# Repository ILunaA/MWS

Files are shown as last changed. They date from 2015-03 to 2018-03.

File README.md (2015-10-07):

MWS
===

Arduino code for a Mobile Weather Station

This is using the SparkFun Weather Shield (https://www.sparkfun.com/products/12081).

Full building manuals in English, Sinhalese and Tamil are found here (along with some display/presentation materials):
http://www.iwmi.cgiar.org/resources/mobile-weather-stations/

There is a Google Group at: IWMIMWS@googlegroups.com

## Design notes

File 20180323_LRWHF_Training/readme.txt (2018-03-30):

This code was made during the training in Sri lanka by the participants.
It adds Dewpoint reporting, heat Index and rain30min.

This is made for non GSM enabled setup (i.e. Arduino Mega, Weather Shield and GPS connected to it).

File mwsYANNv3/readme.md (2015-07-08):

General info about the set up:
- Arduino Mega (x1)
- Sparkfun.com Weather Shield (https://www.sparkfun.com/products/12081)

Optional (plug n play):
- Sparkfun.com (https://www.sparkfun.com/products/9530)
- Generic LCD16x02 with I2C adaptor (more here: http://arduino-info.wikispaces.com/LCD-Blue-I2C)

Required male-to-male cables:
- I2C sensors: Weather Shield A4 to Arduino Mega Pin20 (SDA)
- I2C sensors: Weather Shield A5 to Arduino Mega Pin21 (SCL)
- I2C LCD SDA to Arduino Mega Pin20 (SDA)
- I2C LCD SCL to Arduino Mega Pin21 (SCL)
- COM GPS: Weather Shield PIN4 to Arduino Mega Pin51
- COM GPS: Weather Shield PIN5 to Arduino Mega Pin50

GPS "soft" switch mode:
- Communicates through D4/D5 (same as Arduino Uno R3)
- Power Control through D6 (same as Arduino Uno R3)
- D4/D5/D6 on Arduino Uno (spec sheet: T0/T1/AIN0)
- D7/D6/D5 on Arduino Mega (spec sheet: T0/T1/AIN1*)

*could not find AIN0 pin number in the Mega spec sheet

From https://www.arduino.cc/en/Reference/SoftwareSerial :
- Not all pins on the Mega and Mega 2560 support change interrupts
- so only the following can be used for RX: 
- 10, 11, 12, 13, 14, 15, 50, 51, 52, 53, 
- A8 (62), A9 (63), A10 (64), A11 (65), A12 (66), A13 (67), A14 (68), A15 (69).

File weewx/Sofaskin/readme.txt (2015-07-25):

Arduino restarts each time the Serial port is opened
----------------------------------------------------

Try:
A 10microF capacitor between pin RESET and pin GND to disable that function hardware side.
http://arduino.stackexchange.com/questions/439/why-does-starting-the-serial-monitor-restart-the-sketch

Copy mws.py in $weewxroot/bin/user/ (in RPI it will be /home/weewx/bin/user/) 

Add to $weewxroot/weewx.conf (in RPI it will be /home/weewx/weewx.conf):
------------------------------------------------------------------------

station_type = MWS #was: Simulator

##############################################################################

[MWS]
    
    # Use a non standard driver called mws
    driver = user.mws
    # Give a 5 minute interval for data storage
    loop_interval = 300
    # RPI has this port detected
    port='/dev/ttyACM0'

##############################################################################

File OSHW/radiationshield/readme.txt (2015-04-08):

http://www.thingiverse.com/thing:83969

Description

A Stevenson screen is an outdoor shelter for your meteorological sensors, such as those that come along with your electronic home weather station. The World Meteorological Organization (WMO) agreed standard for the height of the screen is between 1.25 m (4ft 1 in) and 2 m (6ft 7 in). Its purpose is to provide a standardized environment in which to measure temperature, humidity, dew point and atmospheric pressure. The louvered design allows for the instrument to be sheltered from direct sunlight and rain, yet air is able to flow through the screen unrestricted.

Instructions

Print out one top-part and one bottom-part, and then as many middle-parts as necessary. The parts are designed to snap together (inspired by tbuser's Pin Connectors), so no tools required for assembly. The Stevenson screen is designed to be placed on a pole; one wood-screw and a washer required. The pole in the pictures is a Kelleher 6 ft white vinyl coated closet pole acquired from a local home improvement store.

IMPORTANT: Please print in WHITE color in accordance to the WMO agreed standard.

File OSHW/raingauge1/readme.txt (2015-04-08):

http://www.thingiverse.com/thing:298411

Description

Add your own hall/reed sensor and magnet and of-course the electronics and you can create a remote rain sensor system.

Suggested electronics; Arduino & A1301 hall effect sensor.

See: http://playground.arduino.cc/Code/HallEffect

Included funnel & box for sensor.

You might want to tweak the box size so that the funnel fits over the box.

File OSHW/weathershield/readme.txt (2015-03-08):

This is Sparkfun Weather Shield blueprints, an electronic engineer can build or order a factory to make such circuits for you.

Downloaded from:
https://www.sparkfun.com/products/12081

In Sri Lanka, A&T Labs (http://www.atlabslanka.com/) has some.

on March 8th, 2015

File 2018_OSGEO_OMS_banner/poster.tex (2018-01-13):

\documentclass[25pt, margin=0mm, innermargin=15mm, blockverticalspace=15mm, colspace=15mm, subcolspace=8mm]{beamer}
\geometry{paperwidth=40cm,paperheight=181cm}

% to stretch boxes over whole paper with custor paper size
\makeatletter
\setlength{\TP@visibletextwidth}{\textwidth-2\TP@innermargin}
\setlength{\TP@visibletextheight}{\textheight-2\TP@innermargin}
\makeatother

\usepackage{fix-cm}  
\makeatletter
\newcommand\HUGE{\@setfontsize\Huge{80}{90}}
\makeatother

\usepackage{wrapfig}

\definecolor{textcolor}{HTML}{000000}
\definecolor{colorOne}{HTML}{4cbf5d}
\definecolor{colorTwo}{HTML}{dddddd}
\definecolor{colorThree}{HTML}{12343a}

\hypersetup
{
    pdfauthor={Y. Chemin},
    pdfsubject={},
    pdftitle={Open Monitoring Systems Working Group},
    pdfkeywords={}
}

\graphicspath{{images/}{logos/}}

\usepackage[percent]{overpic}
\usepackage{tikz}
\tikzset{
  every overlay node/.style={
    draw=white,fill=white,rounded corners,anchor=north west,
  },
}
% Usage:
% \tikzoverlay at (-1cm,-5cm) {content};
% or
% \tikzoverlay[text width=5cm] at (-1cm,-5cm) {content};
\def\tikzoverlay{%
   \tikz[baseline,overlay]\node[every overlay node]
}%

\begin{document}

\tikzoverlay at (-1.2cm,1.2cm) {
\begin{tikzpicture}
   % NODES
   \node (r0) at (40.0,  0.0) {}; % root
   \node (s0) at (20.0, -160.0) {}; % extreme
   \node (s1) at (40.0, -180.0) {}; % extreme

   % DRAW TREE
   \fill[fill=colorThree,colorThree] (r0.center)--(s0.center)--(s1.center);
   \path[draw] (r0)--(s0);
   \path[draw] (s0)--(s1);
   \path[draw] (s1)--(r0);

   % NODES
   \node (r1) at (-0.1,  -100.5) {}; % root
   \node (s10) at (40.3, -220.0) {}; % extreme
   \node (s11) at (50.0, -165.0) {}; % extreme

   % DRAW TREE
   \fill[fill=colorOne,colorOne] (r1.center)--(s10.center)--(s11.center);
   \path[draw] (r1)--(s10);
   \path[draw] (s10)--(s11);
   \path[draw] (s11)--(r1);

\end{tikzpicture}
}

\tikzoverlay at (5cm,-35cm){
\begin{tikzpicture}[overlay]
\node at (current page.south west) [above right, inner sep=0,outer sep=0]
	{};
\end{tikzpicture}
}

\tikzoverlay at (5cm,-55cm){
\begin{tikzpicture}[overlay]
	\node at (current page.south west) [above right,text width=40cm,align=left] {\HUGE{\textbf{\color{colorThree}Open \\Monitoring \\Systems \\Working Group}}};
\end{tikzpicture}
}

\tikzoverlay at (5cm,-70cm){
\begin{tikzpicture}[overlay]
	\node at (current page.south west) [above right,text width=40cm,align=left] {\Huge{\color{colorThree}https://wiki.osgeo.org/wiki/Open\_Monitoring\_Systems\_Working\_Group}};
\end{tikzpicture}
}

\tikzoverlay at (-1.2cm,-181cm){
\begin{tikzpicture}[overlay]
\node at (current page.south west) [above right, inner sep=0,outer sep=0]
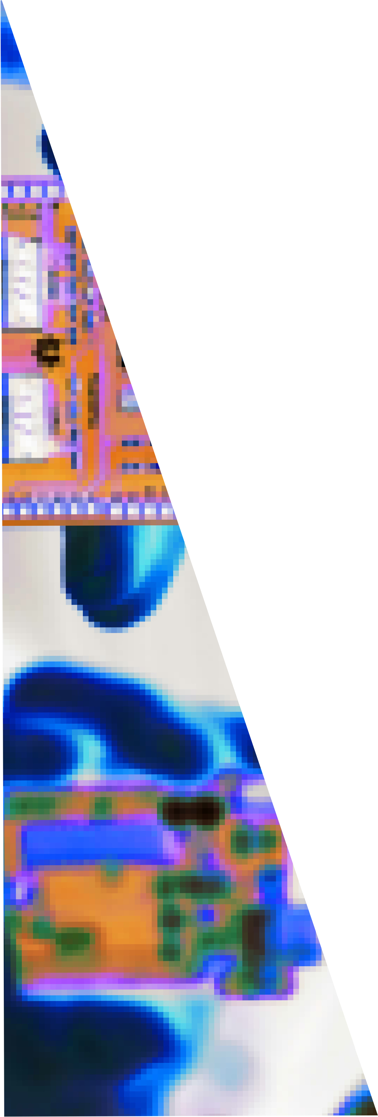
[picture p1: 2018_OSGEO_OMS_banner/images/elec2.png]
	{};
\end{tikzpicture}
}

\tikzoverlay at (-1.2cm,1.2cm) {
\begin{tikzpicture}[overlay]
	\draw [draw=green,thick] (0,-100) (20.0,-160.0);
\end{tikzpicture}
}
%%%%%%%%%%%%%%%%%%%%%%%%%%%%%%%%%%%%%%%%%%%%%%%%%%%%%%%%%%%%%%%%%%%%%%%%%%%%%%%%

\end{document}

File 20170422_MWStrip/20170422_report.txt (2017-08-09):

UO_NUWARAWEWA_SALIYAPURA:
1 - Concrete for raingauge upgrade not made.
2 - Station running.
3 - Signs of aging of external sensors, but still running.
4 - SD card has empty files (why? TODO: check updated code from Lahiru/David trips
5 - We cleaned the rain gauge and solar panels and manually tripped the rain gauge about 70 times to test the threshold value and see if a message was sent. This data point should be ignored.

UO_MAHAKANADARAWA:
1 - Concrete for raingauge upgrade not made.
2 - Station reset, running after replacing the solar charger. 
3 - Wire connections to solar charger must be pushed all the way to the back of the connection sockets to achieve a good connection. Station was previously not receiving adequate power due to a poor connection to charger. This was tested with a multimeter.
4 - Signs of aging on external sensors, but still operational.
5 - Nothing useful in SD card
6 - Solar panel reoriented to face west, which was least blocked by trees. Sunlight will strike more directly, but only afternoons.

THIRAPPANE_FARM:
1 - Concrete for raingauge upgrade not made.
2 - Solar charger was set to mode 3 and not mode 16
3 - Station reset, solar charger set to mode 16, running.
4 - Sensors less aged, their cables more.
5 - SD card not found by laptop, nor mobile, must be broken, was replaced.
6 - Screws on box were too small and not holding box shut, replaced.

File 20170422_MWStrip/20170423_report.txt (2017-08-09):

UO_ATHURUWELLA:
1 - Concrete for raingauge upgrade not made.
2 - Station reset, running after fitting the cables again into the solar charger output.
3 - Signs of aging of external sensors, but still running.
4 - SD card has empty files, but station has been switched off most of the time. 
5 - SIM card has 1090LKR inside still.
6 - Clean rain gauge internals, solar panels are also clean and manually tripped the rain gauge about 50 times to test the threshold value and see if a message was sent. We did not receive it. 
7 - Planned to return on Monday with journalists.
8 - Added a GSM antenna inside, upated code, initialising message received, but once closed box, the manual tipping alert was not received. Will change external antenna.

UO_LABUNORUWA_WEWA_N_WANA:
1 - UO was abandoned more than a year ago (source: neighbour)
2 - We found that wind sensors where vandalised and the moving parts removed
3 - we unbolted the main frame holding solar panel + box and brought it back in the car.
4 - This station name should be removed from list
5 - This system was still working inside (Power optimal, Arduino on, GSM OK), but data logger had not meaningful info stored.

SRI_SADANANDA_PIRIVENA:
1 - The power supply was on MODE 17, we put it back to MODE 16 for automatic operation.
2 - Arduino powered optimally
3 - GSM900a external board (small size) is blinking but not report. SIM card dead, replaced by UO_LABUNORU_WENA_N_WANA card (#4: 0773260142)
4 - Even after replacement of SIM card, no initiliazation message
5 - TODO: return with box salvaged from UO_LABUNORUWA_WEWA_N_WANA, and make use of that system.

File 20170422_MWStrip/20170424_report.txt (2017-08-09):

UO_ATHURUWELLA:
1 - Concrete for raingauge upgrade not made. They know now, and will make (when?).
2 - Station reset from A'Pura hotel, but stuck again on the site, finally running after changing the whole external antenna. Removed internal antenna.
3 - Journalists came the whole morning, they got some talks and practiced building themselves.

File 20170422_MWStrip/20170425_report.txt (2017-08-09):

UO_ATHURUWELLA:
1 - Concrete for raingauge upgrade not made. They know now, and will make (when?).
2 - At 1PM station started to have a raingauge glitch, reported rainfall 2500 mm/h about in the next 3 hours. Fixed by installing new raingauge (rectangle, old one).

SRI_SADANANDA_PIRIVENA:
1 - Used the box from UO_LABUNORUWA_WEWA_N_WANA, installed it there.
2 - the old box (black VCR) has suffered water inside, I might discard it here after recovering electronics from it.

NALLAMUDAWA_MAWATHAWEWA:
1 - Recovered the box today from the station.
2 - upgraded the capacitors on the regulator out
3 - Box working in hotel, will deliver tomorrow on site.

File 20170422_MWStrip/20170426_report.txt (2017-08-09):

UO_ATHURUWELLA:
1 - Concrete for raingauge upgrade to be cast tomorrow.
2 - At 12.30 station started to have a raingauge glitch, reported rainfall 2500-4000 mm/h about in the next 3 hours. Got the station to the hotel.
3 - Changed Arduino, added a passive cooler to the chip.
4 - Made holes in the box and added a PC fan, there is less place, so I had to re-manage the location of everything but the batteries.
5 - Will deliver tomorrow and check the concrete work, maybe install the WMO raingauge.

NALLAMUDAWA_MAWATHAWEWA:
1 - Delivered the working box on site.

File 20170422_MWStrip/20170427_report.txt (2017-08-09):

UO_ATHURUWELLA:
1 - Concrete work done today, will go and install WMO-certified raingauge tomorrow.

NALLAMUDAWA_MAWATHAWEWA:
1 - Took the box for service, it did not report this morning.
2 - Changed solar controller, will see if it reports tomorrow morning, then will send it back to field. 

Mahaweli office (80.298011,8.156554, Contact Wajira Mrs, through Lal Muthuwatta):
1 - Took one of the first weather stations to service, it does not have GSM capabilities, just data logging.
2 - Added a regulator to 5V, it was reporting only 13.00 to 14.00, reduced reporting from 5 mins to 1 hour.

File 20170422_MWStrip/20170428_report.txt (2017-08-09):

UO_ATHURUWELLA:
1 - Installed WMO-certified raingauge. All the UO was busy all morning... :-)
2 - Installed the power line from the building and wired it to weather station.

NALLAMUDAWA_MAWATHAWEWA:
1 - Failure again of the solar controller this morning.
2 - Worked on it this afternoon and evening.  

Mahaweli office (80.298011,8.156554, Contact Wajira Mrs, through Lal Muthuwatta):
1 - Returned the weather station, took contacts with tech guys there.
2 - Emailed tech guys and Mrs Wajira further instatructions to upgrade their system.

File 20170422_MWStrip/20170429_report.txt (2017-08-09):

NALLAMUDAWA_MAWATHAWEWA:
1 - Installed station this morning

UO_ATHURUWELLA:
1 - Changed the GPS this morning as it was reporting around 12.30 instead of early morning with 2000-00-01 as a timestamp.
2 - Arrived in Colombo and got another bug message of 321mm/h my guess is that the box is too small, so too warm, we have temperature in the shade of 40 degrees Celsius, we might reach the maximum operation temperature range of the circuit boards as they are not "industrial grade". 
3 - Recommendation 1 for this set up:
I brought back UO_LABUNO solar panel frame, it has a 300x250x120 electric box (IP65) support frame soldered into it,  one could get that from any electrical shop and set it up in replacement of the now too small box, with an additional fan and proper circulation. this will reduce the likelihood of IRQs jumping. 
4 - Recommendation 2 for this set up:
Also, I believe the direct connection of the main power line to the 5V input of the Arduino Mega is giving the system some issues as electric power is often dropped for few hours a day. I have set up a regulator already, but it may not be enough to provide smooth transitions in power in and out.

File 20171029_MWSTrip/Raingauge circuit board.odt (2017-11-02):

Weather sensors with OSHW micro-controllers

Connectivity and circuit-board possibilities

Introduction

We are looking at setting up some basic circuit board connectivity for weather sensors. Since temperature (i.e. DS18B20), humidity (DHT11/22), pressure (BMP180) are very widely covered by online tutorials, and have several open sourced circuit boards available for perousing and PCB making (for example see Sparkfun, 2017), we will concentrate on external sensors, namely rain gauge, wind speed and velocity. Luckily, those three types of sensors, in their simplest incarnations are all reed switch based. A reed switch is a set of two connector bits that are touching each other all the time, unless in the proximity of a magnetic field. Bringing a magnet in the proximity of the reed switch, disconnects the two parts and opens the circuit, thus interrupting power. In the case of external weather sensors, the sensor is a moving part and carries a magnet inside. The wind velocity sensor counts how many turns per amount of time for example. Each time the moving part goes above a reed switch, a signal is sent inside the microcontroller, the number of signals are recorded within the micro-controller by an always listening sub-system called an IRQ (Interrupted Request), a hardware signal sent to the processor that temporarily stops a running program and allows a special program, an interrupt handler, to run instead. The program inside the micro-controller allocates an IRQ function to the PIN to which the sensor reed switch is connected.

The wind direction is different since it is a flower of 8 or 16 reed switches and the internal circuit board of the sensor sends a step-based power strength, which is giving certain values proportional to the wind direction.

The rain gauge is a simple counter, each IRQ is a volume of rainfall received in the tipping bucket, which is proportional to the height of rainfall (mm) in function of the surface area of the rain gauge and the time elapsed.

Arduino and raingauge

Arduino can enable IRQs on its digital pins. The function digitalPinToInterrupt() permits to enable the connection of the pin to the interrupt process. The function attachInterrupt(), actually sets what is happening when the IRQ is triggered (power up: rising, power down: falling) and received at the pin number. Often a function is triggered to accumulate a count of actions (e.g. reed switch clicks in our case).

Simple case: reed switch connection

In this case, the power is given to the Arduino Nano through the 5V VIN pin and the GND round pin. On the way, the reed switch of the rain gauge (or of the anemometer) is plugged from pin D2 to pin GND.

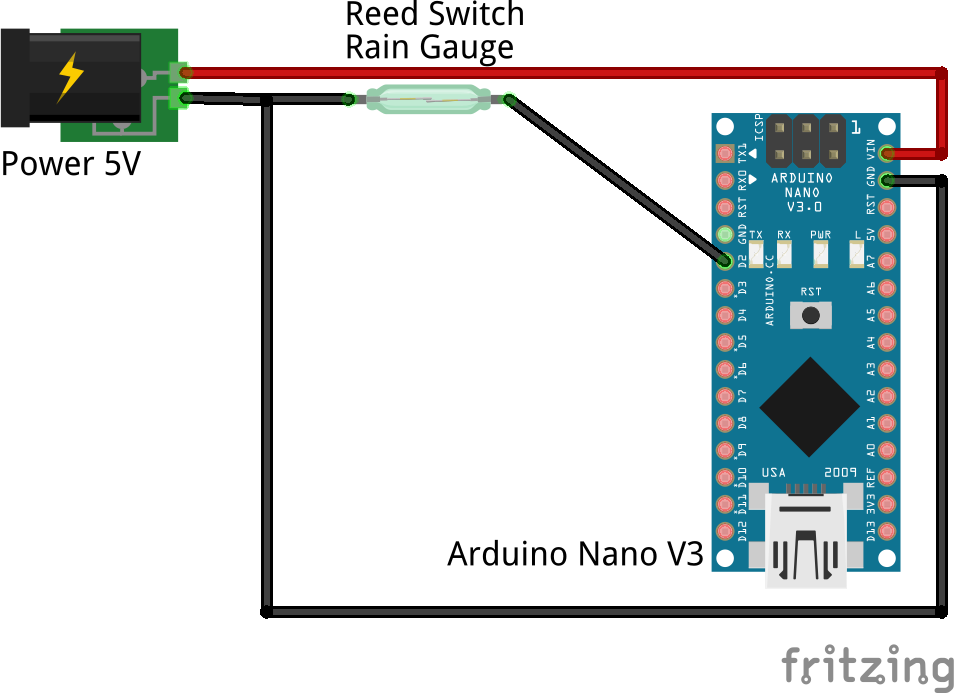
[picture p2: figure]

Figure 1: Connecting a reed switch to Arduino

The corresponding Arduino code is like this:

//Set PIN 2 as data input pulled up

pinMode(2, INPUT_PULLUP);

//Attach IRQ to PIN 2 and tells it to run function addRain()
attachInterrupt (digitalPinToInterrupt(2), addRain, FALLING);

//Function addRain() adds to the daily tip count

volatile tipToday;

addRain(){

tipToday+=1;

}

The reality of working in less than optimal conditions concerning the power supplies makes this case a less workable set up. Power supplies are rarely controlled and precise.

IRQ Debouncing

IRQs are sometimes sensitive to unreliable power input, thus triggering when no signal is sent (i.e. rain is falling in a clear sky day). To remedy to this, hardware debouncing is required by absorbing power input fluctuations before it influences the IRQ. An example of such setup is found below.

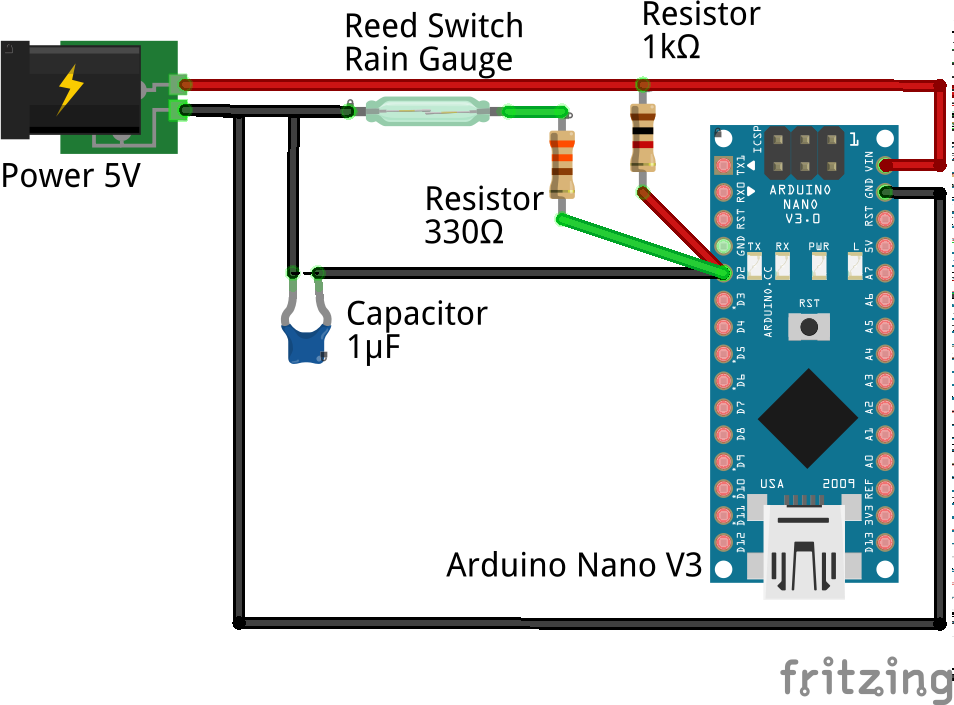
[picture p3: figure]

Figure 2: Debouncing a reed switch with 0.1uF (adapted from MySensors, 2017)

The rain gauge is connected to the Pin D2, which is setup as an IRQ in the Arduino code.

//Set PIN 2 as data input

pinMode(2, INPUT);

//Attach IRQ to PIN 2 and tells it to run function addRain()
attachInterrupt (digitalPinToInterrupt(2), addRain, FALLING);

//Function addRain() adds to the daily tip count

volatile tipToday;

addRain(){

tipToday+=1;

}

Miser (2017) mentioned that a 1 uF capacitor between the signal and ground is a solution to the Sparkfun weather shield phantom rain. Looking at the Sparkfun Weather Shield schematics, we find that though the resistors are set up, no capacitor is available. Thus there is no signal debouncing.

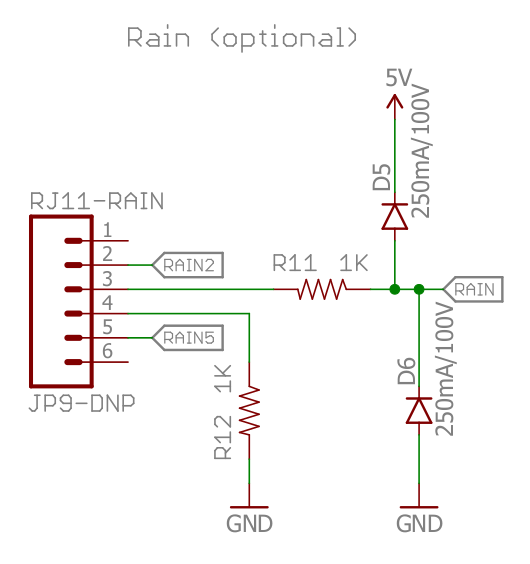
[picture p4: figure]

Figure 3: Raingauge RJ11 connection schematics from Sparkfun website.

Field set up #1: jump the reed switch

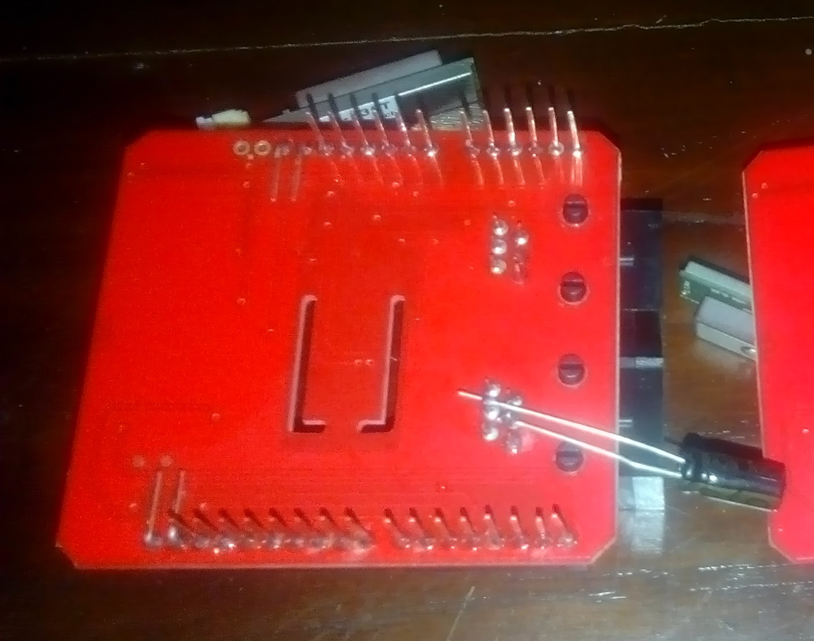
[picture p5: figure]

Figure 4: Jumping the reed switch with 1nF electrolytic capacitor

This setup reported apparently well for 3 days, initially leading us to think it was a progress. We will have to determine if the capacitor was overloaded or if it was just 3 days of cloudy conditions where no solar charging overload happened.

Field setup #2: Debounce on Pin D2

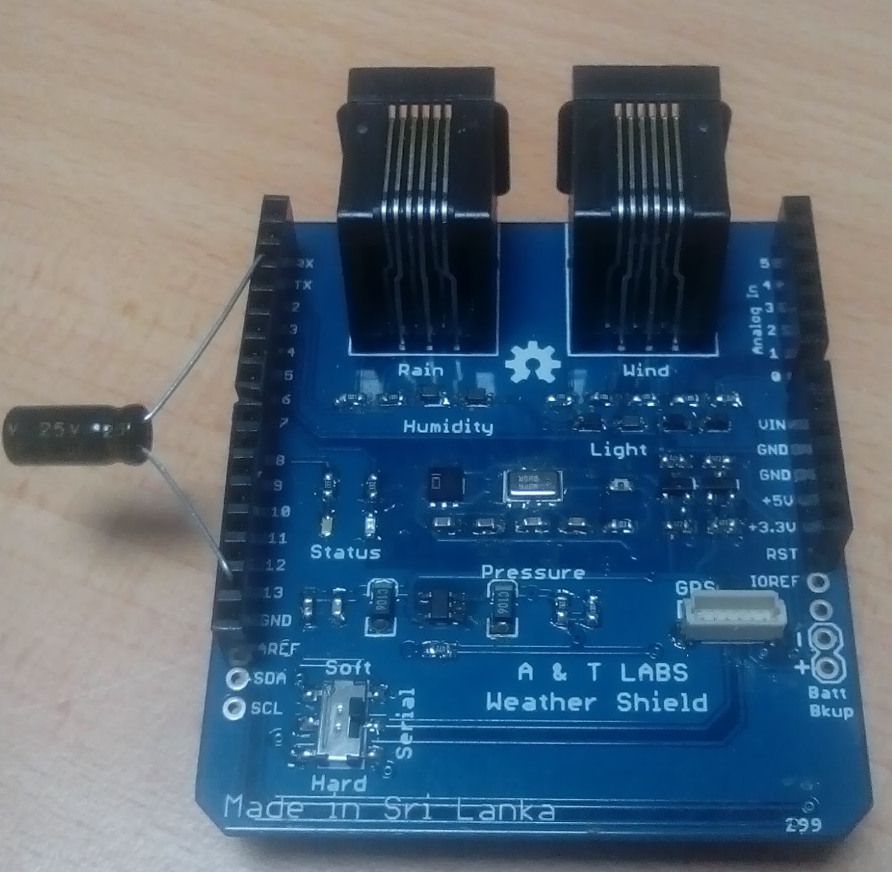
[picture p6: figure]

Figure 5: Debounce on Pin D2 (Rain IRQ)

After the failing of the Field setup #1, not knowing yet if it was a overloading of the capacitor (i.e. a good location on the board but a too small value) or not the right place to debounce effectively, we reassessed the circuit and looked for another potential bypass location to set up the capacitor. This time, using the IRQ pin D2 receiving the FALLING signal from the reed switch.

ESP8266 variation

The ESP8266 can be frugal in energy consumption if the WiFi onboard is switched off, around 50mA. It can be programmed within the Arduino IDE with the same coding language. Literally speaking, the connectivity is identical to an Arduino, though the programming needs to care for few different things.

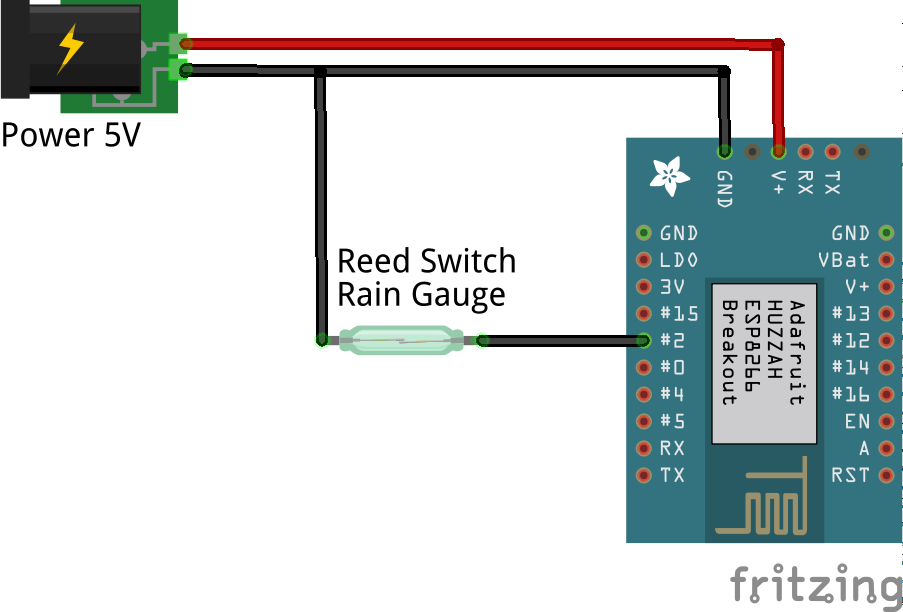
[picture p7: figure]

Figure 3: ESP8266 connected to a reed switch

The following LUA code permits to count the number of tips (Benlo, 2017). The IRQ is triggered on GPIO 02 when the power transitions from HIGH to LOW. The interrupts calls a counter function quoted below. The delay timer makes sure that any secondary pulse within 250ms will be discarded.

-- Count pulses on GPIO2

count = 0
delay = 0
gpio.mode(9,gpio.INT)

function counter(level)
x = tmr.now()
if x > delay then
delay = tmr.now()+250000
count = count + 1
end
end
gpio.trig(9, "down",counter)

References

Benlo, 2017. ESP8266 rain gauge. http://benlo.com/esp8266/esp8266Projects.html#rain

Miser, 2017. ESP8266 weather final test step 2-2. https://www.miser-tech.com/2017/08/esp8266-weather-final-test-step-2-2/

MySensors, 2017. Debouncing a reed switch. https://www.mysensors.org/build/rain

Sparkfun, 2017. Weather Shield Schematic (pdf url) and circuit board files (eagle files zip url), https://cdn.sparkfun.com/datasheets/Dev/Arduino/Shields/Weather%20Shield_V12.pdf
https://cdn.sparkfun.com/datasheets/Dev/Arduino/Shields/Weather%20Shield_V12.zip

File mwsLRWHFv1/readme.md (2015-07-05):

On 5th July 2015, LRWHF, Pelawatte

Note for future use on Windows:
We faced a compiler/upload issue using IDE v1.6.5, on the same PC, IDE v1.0.5 did compile and upload properly.

General info about the setup:
- Arduino Uno R3 (or clone like in www.lakduino.com)
- Sparkfun.com weather shield (https://www.sparkfun.com/products/12081)
Optional:
- Sparkfun.com OpenLog (https://www.sparkfun.com/products/9530)

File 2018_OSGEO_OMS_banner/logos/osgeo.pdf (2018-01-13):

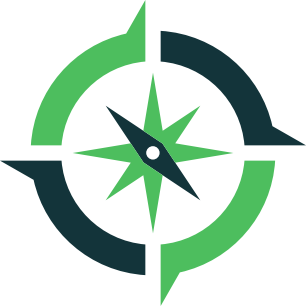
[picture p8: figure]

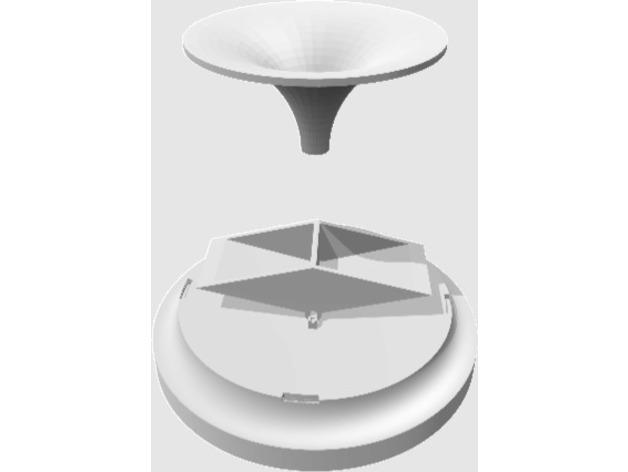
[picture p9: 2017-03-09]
OSHW/raingauge4/images/2400bc910caad1e59801957dded0996e_preview_featured.jpg

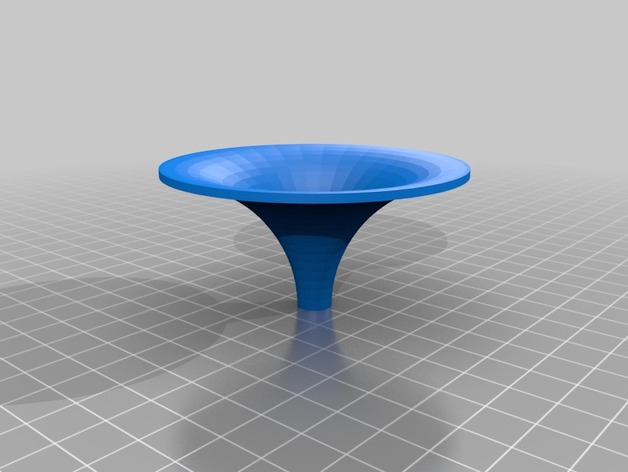
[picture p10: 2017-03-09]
OSHW/raingauge4/images/a9330e3575f6a619bc661684a80c7c6d_preview_featured.jpg

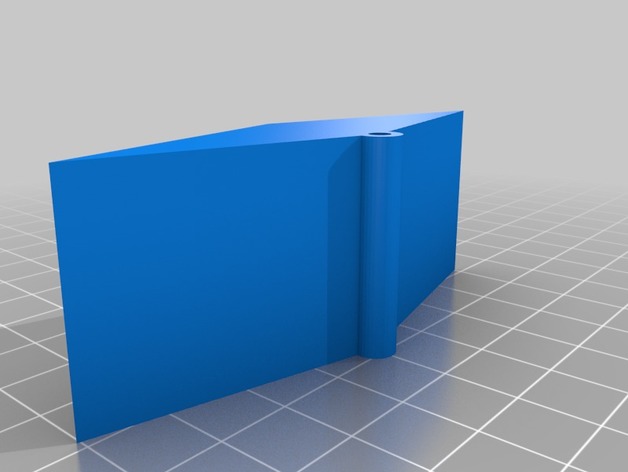
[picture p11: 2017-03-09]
OSHW/raingauge4/images/710c5ddf7db8b5e98056d49471bedbdb_preview_featured.jpg

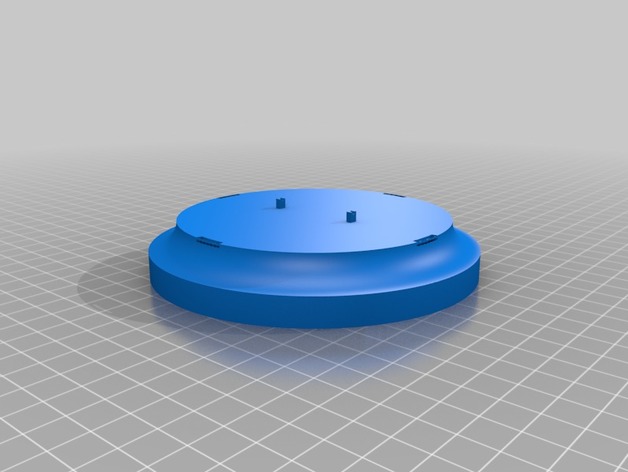
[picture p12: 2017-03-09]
OSHW/raingauge4/images/b1e22cad43c1f7503c7b23d5b3ef9bae_preview_featured.jpg

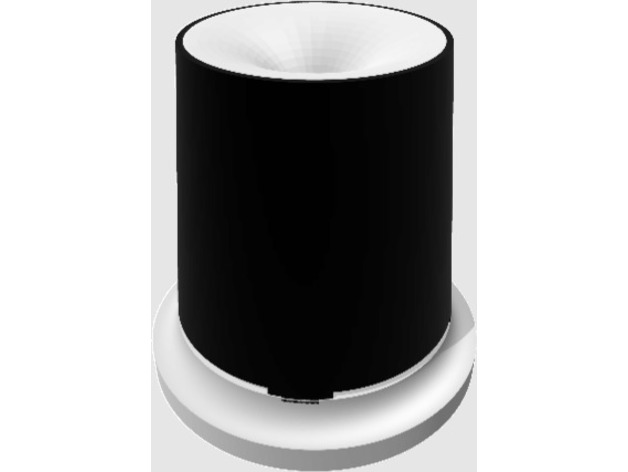
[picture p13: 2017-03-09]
OSHW/raingauge4/images/6628c93c2a38ff42b952c92fc7de512c_preview_featured.jpg

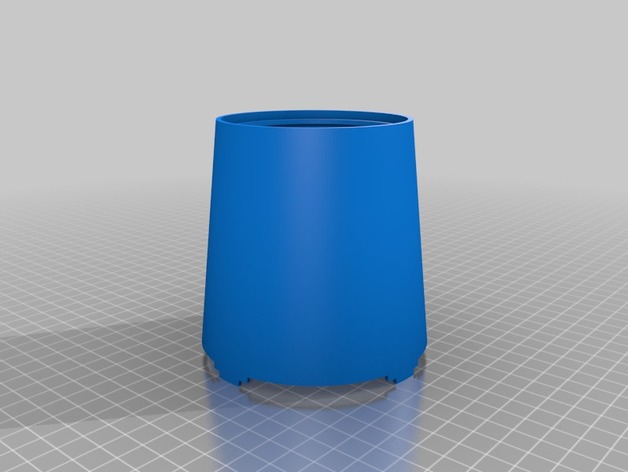
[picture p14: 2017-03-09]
OSHW/raingauge4/images/f6b5cba7ec9136af1e27ceb7a25e8111_preview_featured.jpg

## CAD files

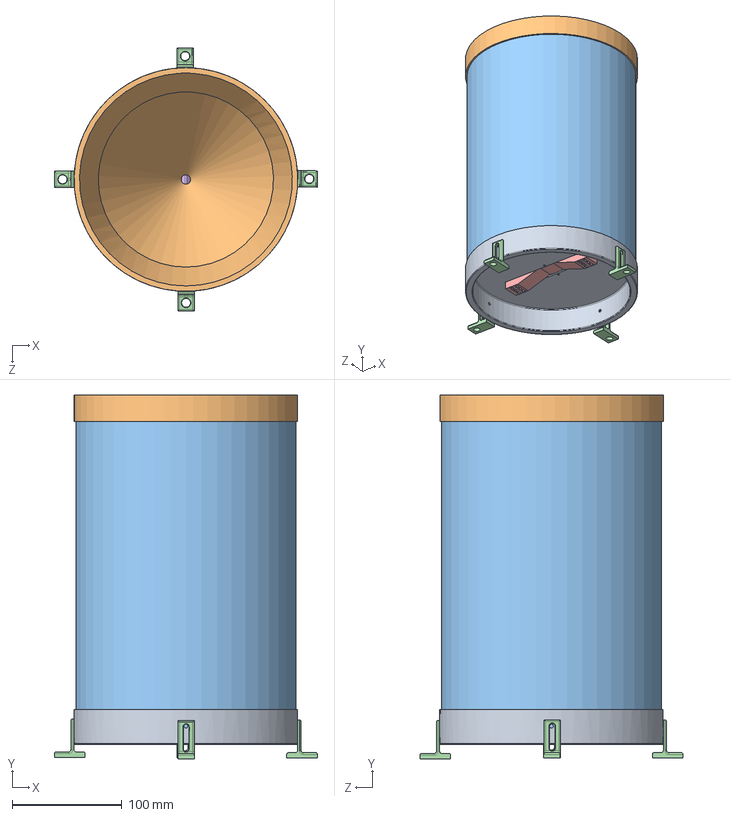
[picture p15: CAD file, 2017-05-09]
OSHW/Pluviometro/RAIN GAUGE.SLDASM
239.8 x 331.4 x 239.7 mm
BOTTOM CAP
COLLECTOR
PVC PIPE
SPACER x 4
SUPPORT
Tic

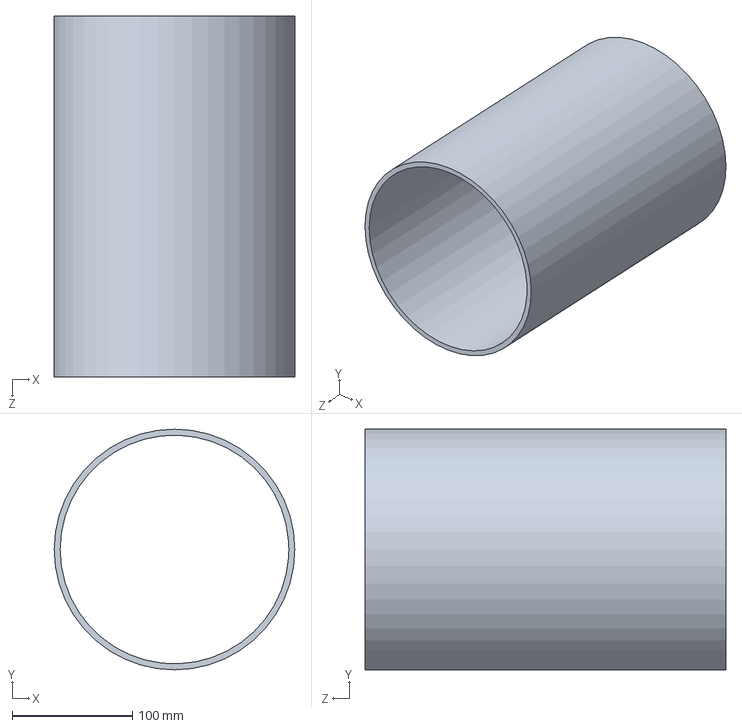
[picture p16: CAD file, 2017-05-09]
OSHW/Pluviometro/PVC PIPE.SLDPRT
200.0 x 200.0 x 300.0 mm

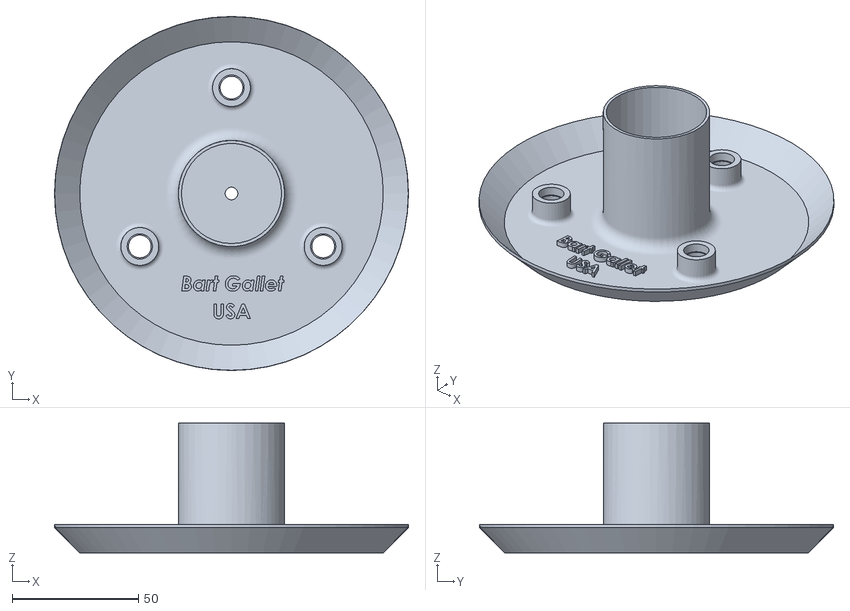
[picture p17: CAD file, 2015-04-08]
OSHW/radiationshield/Bottom_part.STL
140.0 x 140.0 x 51.4

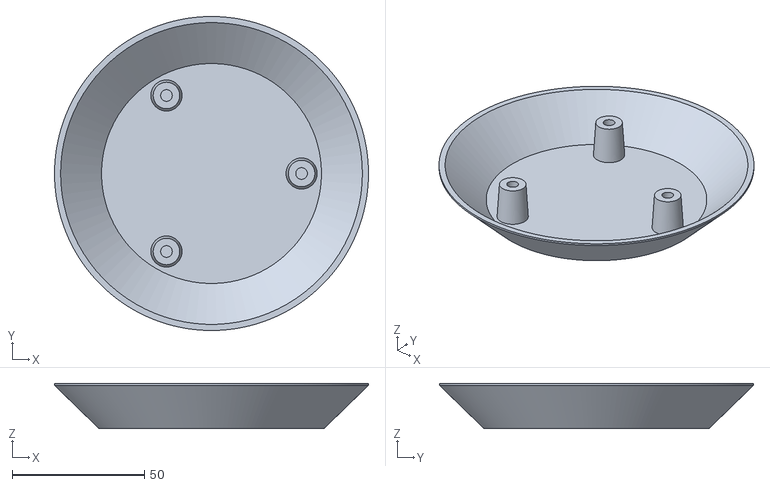
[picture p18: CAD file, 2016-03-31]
OSHW/radiationshield1/Radiation_Shield_For_Weather_Station_Temperature_Humidity/Rad_Shd_Top_V1.stl
118.5 x 118.5 x 17.0

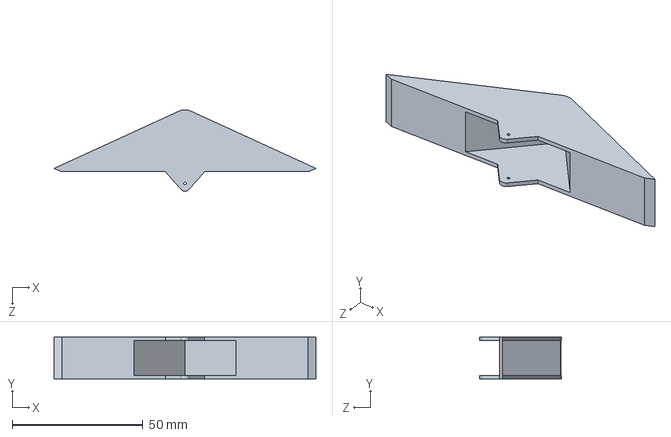
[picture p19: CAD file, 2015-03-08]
OSHW/raingauge/collector - Copy.SLDPRT
100.0 x 16.0 x 31.1 mm

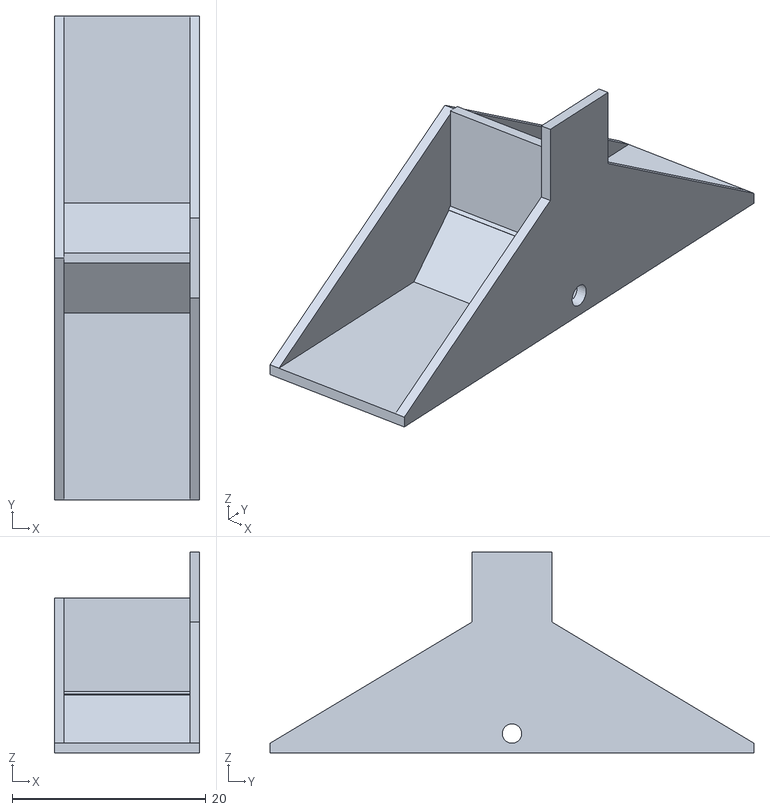
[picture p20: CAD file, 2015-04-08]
OSHW/raingauge1/water-bucket.stl
15.0 x 50.0 x 20.8

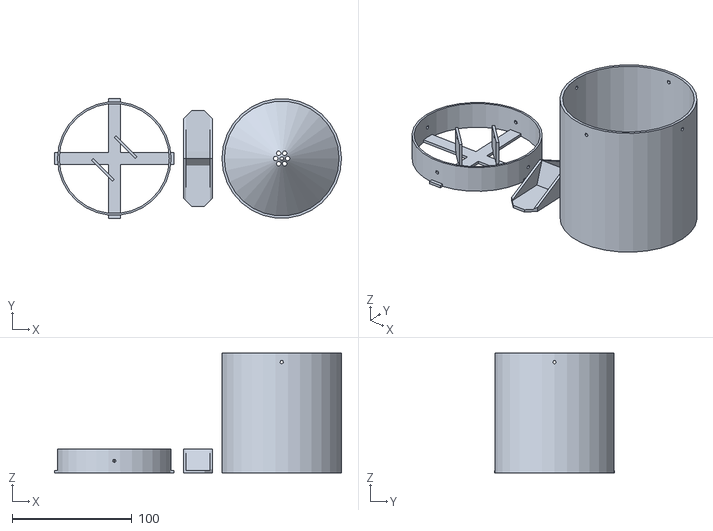
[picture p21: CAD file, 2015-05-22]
OSHW/raingauge2/rainmeter_plate_lowres.stl
240.0 x 100.0 x 100.0

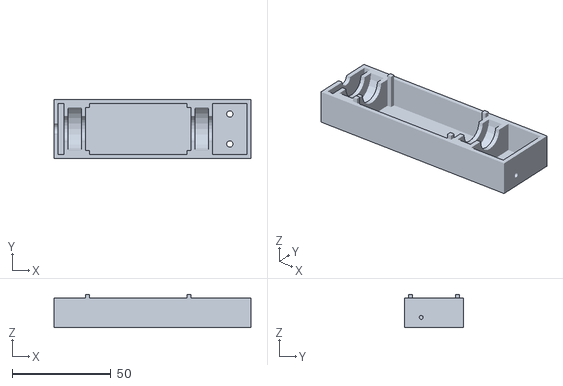
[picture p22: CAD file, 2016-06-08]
OSHW/raingauge3_windspeed/housing2.stl
100.0 x 30.0 x 17.0

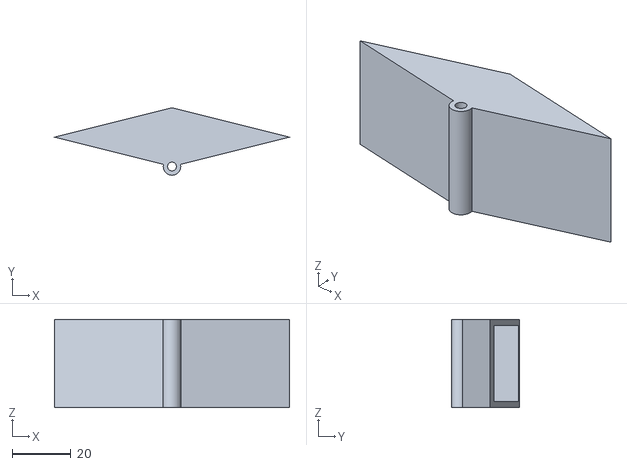
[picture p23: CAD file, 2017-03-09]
OSHW/raingauge4/files/Bucket.stl
80.0 x 23.0 x 30.0

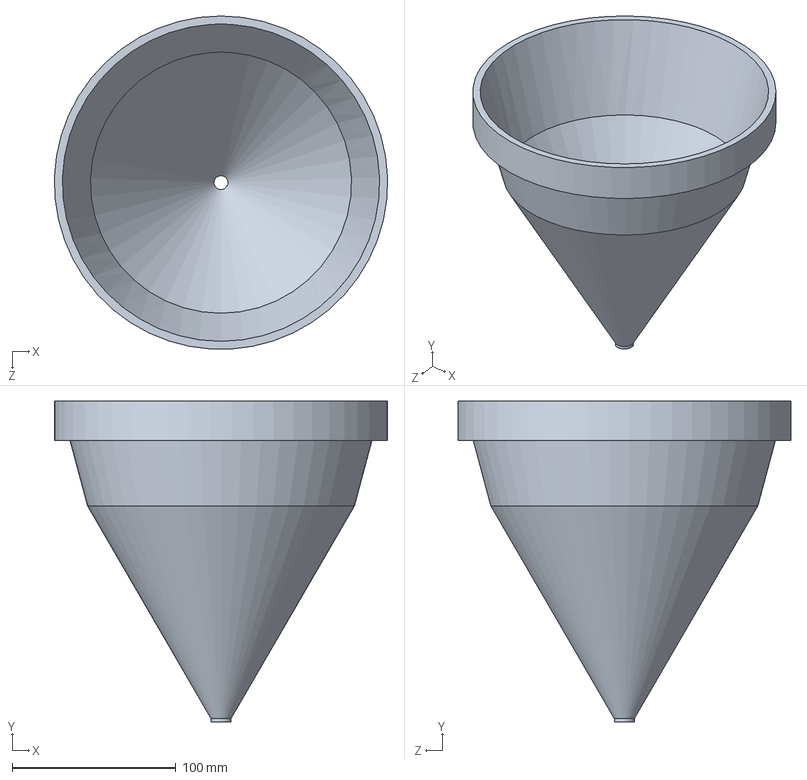
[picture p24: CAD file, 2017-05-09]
OSHW/Pluviometro/COLLECTOR.SLDPRT
203.5 x 196.0 x 203.4 mm

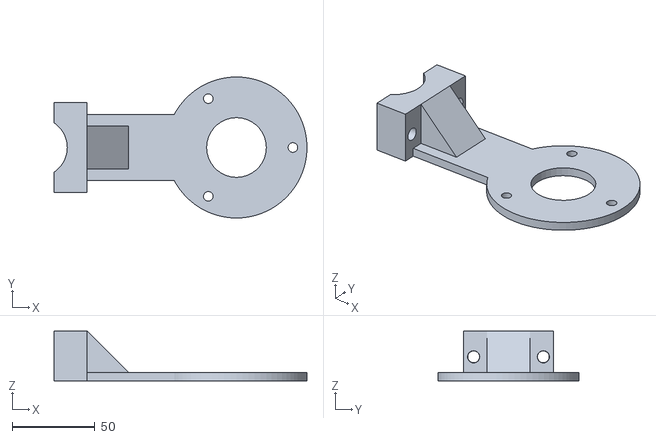
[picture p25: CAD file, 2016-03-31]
OSHW/radiationshield1/Radiation_Shield_For_Weather_Station_Temperature_Humidity/Rad_Shd_Vert_mount_V1.stl
152.5 x 85.0 x 30.0

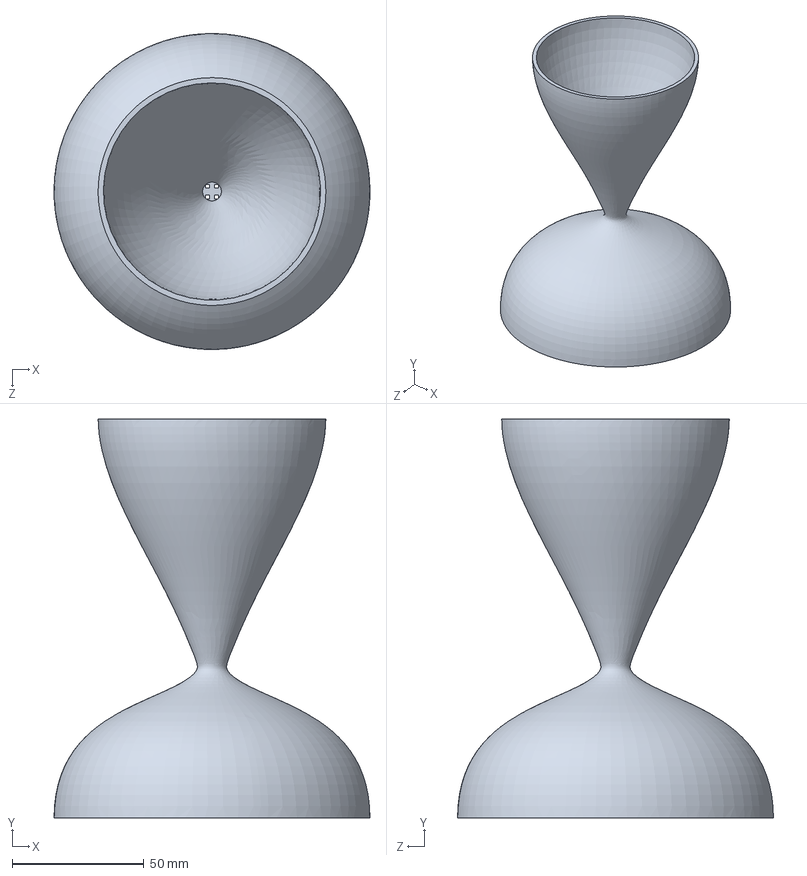
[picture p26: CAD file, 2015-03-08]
OSHW/raingauge/Cover-round.SLDPRT
120.0 x 151.5 x 120.0 mm

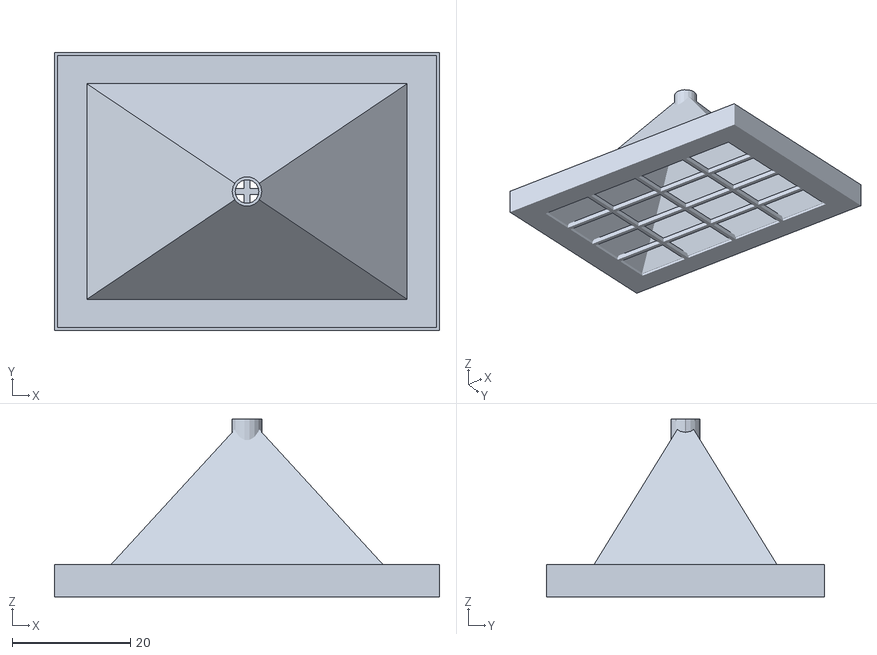
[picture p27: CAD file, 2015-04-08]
OSHW/raingauge1/Cone2.stl
65.0 x 47.0 x 30.0

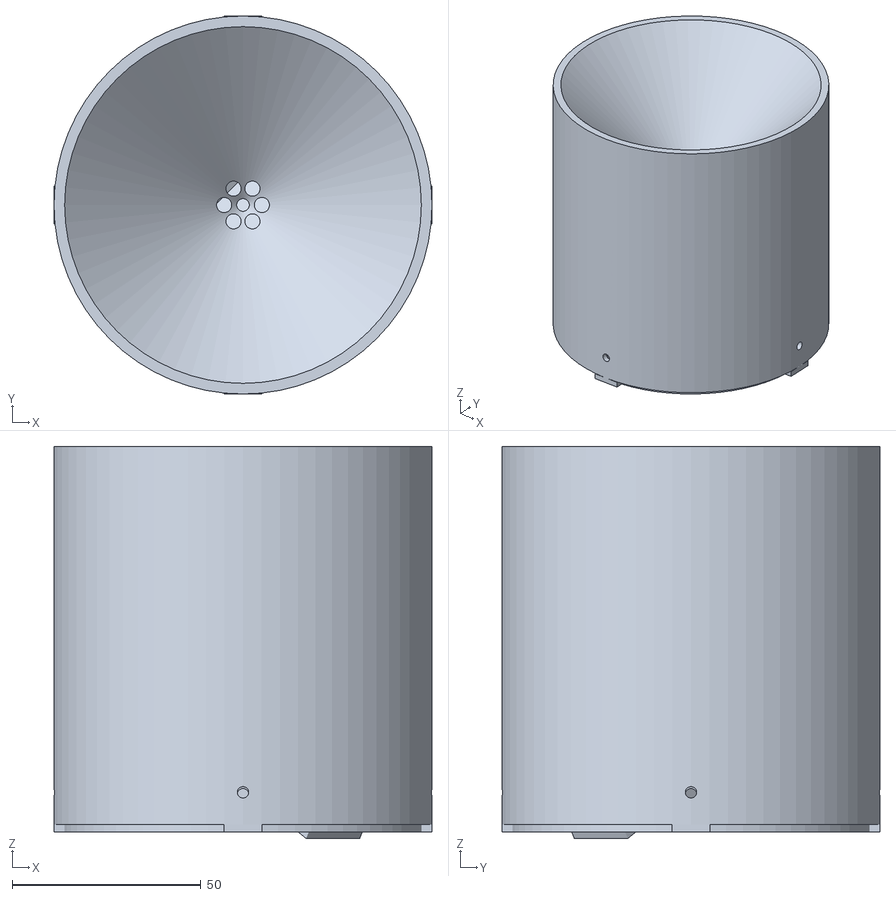
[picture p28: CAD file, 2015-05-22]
OSHW/raingauge2/rainmeter.stl
100.0 x 100.0 x 103.7

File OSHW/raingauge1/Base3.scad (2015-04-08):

$fn = 18;

// lenght & width are inside sizes
module base(length, width, height)
{
	wall=0.5;
	holesize=2;
	step = width/(holesize*holesize*2);	
	// echo(step);
	difference() {
		union() {
			// bottom
			echo("lenght:", length);
			echo("width:", width);			
			cube([length+2*wall,width+2*wall,1],center = true);
			// sides - long
			color("gray") translate([0,width/2+wall-(wall/2), height/2]) rotate([90,0 ,0 ]) cube([length+wall*2,height, wall], center=true);
			color("gray") translate([0,-width/2-wall+(wall/2) , height/2]) rotate([90,0 ,0 ]) cube([length+wall*2,height, wall], center=true);
			// sides - short
			translate([-length/2-wall+(wall/2),0 , height/2]) rotate([0,0 ,90 ])  rotate([90,0 ,0 ]) cube([width+wall,height, wall], center=true);
			translate([length/2+wall-(wall/2),0 , height/2]) rotate([0,0 ,90 ])  rotate([90,0 ,0 ])  cube([width+wall,height, wall], center=true);
			// corners - vertical
			// color("blue") translate([length/2+wall-0.5,width/2+wall-0.5 , 0]) cylinder(r=0.5, h=height, center=false);
			// color("blue") translate([-length/2-wall+0.5,width/2+wall-0.5 , 0]) cylinder(r=0.5, h=height, center=false);
			// color("blue") translate([length/2+wall-0.5,-width/2-wall+0.5 , 0]) cylinder(r=0.5, h=height, center=false);
			// color("blue") translate([-length/2-wall+0.5,-width/2-wall+0.5 , 0]) cylinder(r=0.5, h=height, center=false);

		}
		//mounting holes
		color("red") translate([25,8, 0]) cylinder(h=3, r=2, center=true);
		color("red") translate([-25,8, 0]) cylinder(h=3, r=2, center=true);
		color("red") translate([25,-8, 0]) cylinder(h=3, r=2, center=true);
		color("red") translate([-25,-8, 0]) cylinder(h=3, r=2, center=true);

		// drain holes
		/*
		for (i = [-width/2+step:step:width/2-step]) {
			color("red") translate([length/2,i,2.5]) rotate([0,90,0]) cylinder(h=3*wall, r=holesize, center=true);
			color("red") translate([-length/2,i,2.5]) rotate([0,90,0]) cylinder(h=3*wall, r=holesize, center=true);
		}
		for (i = [-length/2+2*wall:8*wall:length/2-2*wall]) {
			color("red") translate([i,width/2,3]) rotate([90,0,0]) cylinder(h=3*wall, r=1, center=true);
			color("red") translate([i,-width/2,3]) rotate([90,0,0]) cylinder(h=3*wall, r=1, center=true);
		}
		// cable holes
		color("red") translate([0,-width/2,10])  rotate([90,0,0]) cylinder(h=4*wall, r=3, center=true);
		color("red") translate([0,width/2,10])  rotate([90,0,0]) cylinder(h=4*wall, r=3, center=true);
		*/

		// mounting holes
		// color("red") translate([length/2-10,-width/2,height-5])  rotate([90,0,0]) cylinder(h=4*wall, r=2, center=true);
	}
}

base(63,45,60);

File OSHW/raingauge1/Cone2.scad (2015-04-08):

$fn = 18;

module cone(length, width, height, funnel, edge)
{
	difference() {
		union() {
			polyhedron(
				points = [
					[length/2, width/2, 0],
					[length/2, -width/2, 0],
					[-length/2, -width/2, 0],
					[-length/2, width/2, 0],
					[0, 0, height]
				],
				triangles = [
					[3, 2, 1, 0],
					[1, 4, 0],
					[2, 4, 1],
					[3, 4, 2],
					[0, 4, 3]
				]
			);
			// Funnel part
			color("blue") translate([0, 0, height-funnel/2]) cylinder(r=funnel/2,h=funnel-1,center = true);
		}
		// Remove center of pyramide
		translate([0, 0, -1])
		polyhedron(
			points = [
				[length/2, width/2, 0],
				[length/2, -width/2, 0],
				[-length/2, -width/2, 0],
				[-length/2, width/2, 0],
				[0, 0, height]
			],
			triangles = [
				[3, 2, 1, 0],
				[1, 4, 0],
				[2, 4, 1],
				[3, 4, 2],
				[0, 4, 3]
			]
		);
		// Funnel part hole
		color("red") translate([0, 0, height-funnel/2]) cylinder(r=2,h=funnel+2,center = true);
	}
	// Edge
	difference() {
		echo("lenght:", length+(edge*2));
		echo("width:", width+(edge*2));
		color("green")  translate([0, 0, 0]) cube([length+(edge*2), width+(edge*2), 1], center=true)	;
		color("blue")  translate([0, 0, -0.05]) cube([length-2, width-1, 1.2], center=true)	;
	}
	// Grill
	step1=length/4;
	step2=width/4;
	union() {
		for (i = [-length/2+step1:step1:length/2-step1]) {
			translate([i,0 ,0 ]) cube([1, width, 1], center=true);
		}

		for (j = [-width/2+step2:step2:width/2-step2]) {
		 translate([0,j ,0 ]) rotate([0, 0, 90])  cube([1, length, 1], center=true);
		}
	}
	// Lip
	difference() {
		translate([0, 0, edge/2]) cube([length+edge*2,width+edge*2,edge], center=true);
		translate([0, 0, edge/2]) cube([length+edge*2-1,width+edge*2-1,edge+1], center=true);
	}
}

cone(55,37,30, 5, 5);

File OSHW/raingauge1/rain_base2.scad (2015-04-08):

use<triangles.scad>

$fn = 30;

module base(length, width, height)
{
	difference() {
		union() {
			translate([-width/2, -length/2, -2]) cube([width,length,2]);
			translate([width/2-2, 0, 0])  rotate(a=90, v=[0,1 ,0 ]) rotate(a=90, v=[0,0 ,1 ]) Isosceles_Triangle(b=length/2, H=height);
			translate([width/2-1, 0, 0])  rotate(a=90, v=[0,1 ,0 ]) rotate(a=90, v=[0,0 ,1 ]) Isosceles_Triangle(b=length/2, H=height);
			translate([-width/2, 0, 0])  rotate(a=90, v=[0,1 ,0 ]) rotate(a=90, v=[0,0 ,1 ]) Isosceles_Triangle(b=length/2, H=height);
			translate([-width/2+1, 0, 0])  rotate(a=90, v=[0,1 ,0 ]) rotate(a=90, v=[0,0 ,1 ]) Isosceles_Triangle(b=length/2, H=height);

			// big support columns
			color("green") translate([width/2-3.5,5,0]) rotate(a=270, v=[0,1 ,0 ]) rotate(a=60, v=[1,0 ,0 ]) Right_Angled_Triangle(a=6, b=height-16, centerXYZ=[false,true,true]);
			color("green") translate([width/2-3.5,-5,0]) rotate(a=270, v=[0,1 ,0 ]) rotate(a=120, v=[1,0 ,0 ]) Right_Angled_Triangle(a=6, b=height-16, centerXYZ=[false,true,true]);
			color("green") translate([-width/2+3.5,5,0]) rotate(a=270, v=[0,1 ,0 ]) rotate(a=300, v=[1,0 ,0 ]) Right_Angled_Triangle(a=6, b=height-16, centerXYZ=[false,true,true]);
			color("green") translate([-width/2+3.5,-5,0]) rotate(a=270, v=[0,1 ,0 ]) rotate(a=240, v=[1,0 ,0 ]) Right_Angled_Triangle(a=6, b=height-16, centerXYZ=[false,true,true]);
			// small support columns
			// color("green") translate([width/2-3.5,length/2-11,0]) rotate(a=270, v=[0,1 ,0 ]) rotate(a=90, v=[1,0 ,0 ]) Right_Angled_Triangle(a=5, b=height/4, centerXYZ=[fasle,true,true]);
			// color("green") translate([-width/2+3.5,length/2-11,0]) rotate(a=270, v=[0,1 ,0 ]) rotate(a=270, v=[1,0 ,0 ]) Right_Angled_Triangle(a=5, b=height/4, centerXYZ=[false,true,true]);
			// color("green") translate([width/2-3.5,-length/2+11,0]) rotate(a=270, v=[0,1 ,0 ]) rotate(a=90, v=[1,0 ,0 ]) Right_Angled_Triangle(a=5, b=height/4, centerXYZ=[fasle,true,true]);
			// color("green") translate([-width/2+3.5,-length/2+11,0]) rotate(a=270, v=[0,1 ,0 ]) rotate(a=270, v=[1,0 ,0 ]) Right_Angled_Triangle(a=5, b=height/4, centerXYZ=[false,true,true]);

			// calibration posts
			color("blue") translate([0, length/2-20, 0]) cylinder(h=4.5, r=3, center=false);
			color("blue") translate([0, -length/2+20, 0]) cylinder(h=4.5, r=3, center=false);
		}
		// hole for the bucket rod
		color("red") translate([0, 0, height-14]) rotate(a=90, v=[0,1 ,0 ]) cylinder(h=width+5, r=1, center=true);
		color("red") translate([0, 0, height-7]) rotate(a=90, v=[0,1 ,0 ]) cylinder(h=width+5, r=1, center=true);
		color("red") translate([0, 2.5, height-10]) rotate(a=90, v=[0,1 ,0 ]) cylinder(h=width+5, r=1, center=true);
		color("red") translate([0, -2.5, height-10]) rotate(a=90, v=[0,1 ,0 ]) cylinder(h=width+5, r=1, center=true);
		// calibration posts holes
		color("red") translate([0, length/2-20, -3]) cylinder(h=9, r=1.5, center=false);
		color("red") translate([0, -length/2+20, -3]) cylinder(h=9, r=1.5, center=false);
		// mounting holes
		color("red") translate([width/2-7, length/2-5, -3]) cylinder(h=4, r=2, center=false);
		color("red") translate([width/2-7, -length/2+5, -3]) cylinder(h=4, r=2, center=false);
		color("red") translate([-width/2+7, length/2-5, -3]) cylinder(h=4, r=2, center=false);
		color("red") translate([-width/2+7, -length/2+5, -3]) cylinder(h=4, r=2, center=false);
		// cut to top off the piramides
		color("red") translate([0, 0, height-1]) cube([width+2,10,5],center = true);
	}
}


base(60,30,30);

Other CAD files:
OSHW/raingauge3_windspeed/ground_frame_v2.stl
OSHW/raingauge4/files/Outer_Body.stl
OSHW/Pluviometro/BOTTOM CAP.SLDPRT
OSHW/radiationshield1/Radiation_Shield_For_Weather_Station_Temperature_Humidity/Rad_Shd_Fin_V1.stl
OSHW/raingauge1/water-bucket.scad
OSHW/Pluviometro/SPACER.SLDPRT
OSHW/Pluviometro/SUPPORT.SLDPRT
OSHW/Pluviometro/Tic.SLDPRT
OSHW/radiationshield1/Radiation_Shield_For_Weather_Station_Temperature_Humidity/AM2315_mount_V1.stl
OSHW/radiationshield1/Radiation_Shield_For_Weather_Station_Temperature_Humidity/HTM2500_mount_V1.stl
OSHW/radiationshield1/Radiation_Shield_For_Weather_Station_Temperature_Humidity/HTU21D_mount_V1.stl
OSHW/radiationshield1/Radiation_Shield_For_Weather_Station_Temperature_Humidity/Rad_Shd_Base_V1.stl
OSHW/radiationshield1/Radiation_Shield_For_Weather_Station_Temperature_Humidity/Rad_Shd_Horz_mount_V1.stl
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

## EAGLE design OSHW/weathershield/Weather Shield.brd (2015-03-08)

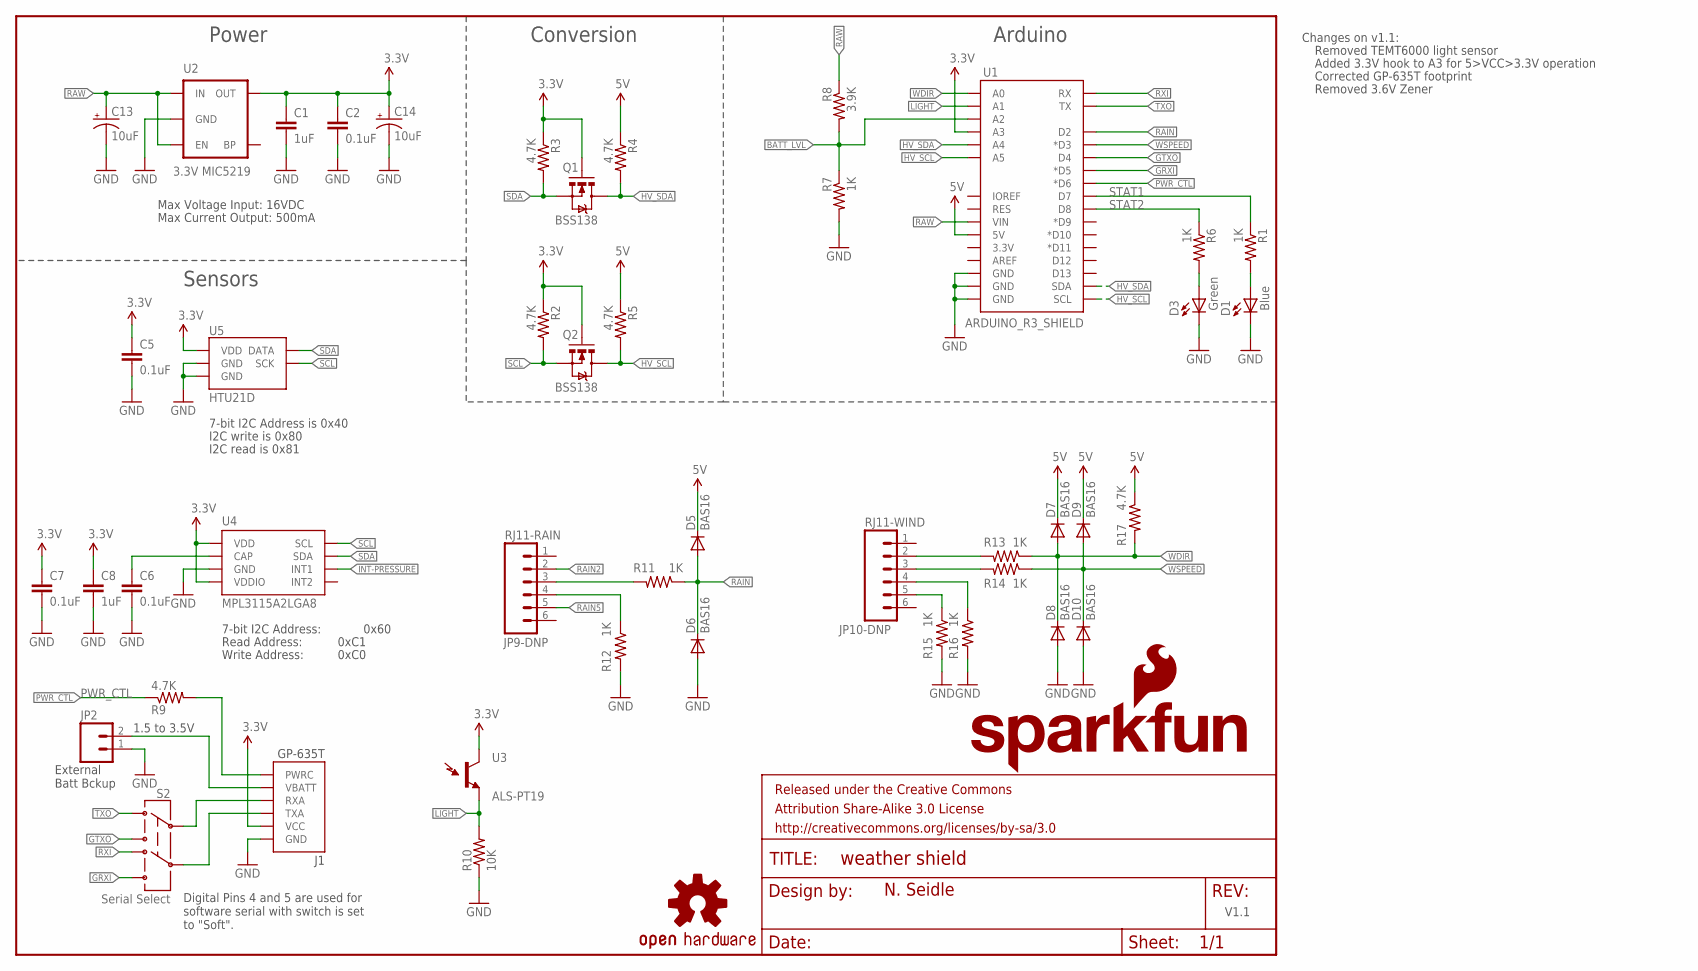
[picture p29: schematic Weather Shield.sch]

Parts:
C1, C8: 1uF; 0603-CAP
C2, C5, C6, C7: 0.1uF; 0603-CAP
C13, C14: 10uF; EIA3216
D1: Blue; LED-0603
D3: Green; LED-0603
D5, D6, D7, D8, D9, D10: BAS16; SOD-323
FRAME1: FRAME-LETTER; CREATIVE_COMMONS
J1: GP-635T
JP2: External Batt Bckup; 1X02
JP9-DNP: RJ11-RAIN; RJ11-6
JP10-DNP: RJ11-WIND; RJ11-6
LOGO1: OSHW-LOGOM; OSHW-LOGO-M
LOGO2: SFE_LOGO_NAME_FLAME.1_INCH; SFE_LOGO_NAME_FLAME_.1
Q1, Q2: BSS138; SOT23-3
R1, R6, R7, R11, R12, R13, R14, R15, R16: 1K; 0603-RES
R2, R3, R4, R5, R9, R17: 4.7K; 0603-RES
R8: 3.9K; 0603-RES
R10: 10K; 0603-RES
S2: Serial Select; AYZ0202
U1: ARDUINO_R3_SHIELD; UNO_R3_SHIELD
U2: 3.3V MIC5219; SOT23-5
U3: ALS-PT19
U4: MPL3115A2LGA8; LGA8
U5: HTU21D

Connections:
3.3V: C1.1, C2.1, C5.1, C7.1, C8.1, C14.A (+), J1.2 (VCC), Q1.1 (G), Q2.1 (G), R2.1, R3.1, U1.A3, U2.5 (OUT), U3.C (C1), U4.1 (VDD), U4.4 (VDDIO), U5.VDD
3V_PWR_CTL: J1.6 (PWRC), R9.2
5V: D5.1 (C), D7.1 (C), D9.1 (C), R4.1, R5.1, R17.1, U1.5V
BATT_LVL: R7.1, R8.2, U1.A2
GND: C1.2, C2.2, C5.2, C6.2, C7.2, C8.2, C13.C (-), C14.C (-), D1.C, D3.C, D6.2 (A), D8.2 (A), D10.2 (A), J1.1 (GND), JP2.1, R7.2, R10.1, R12.2, R15.2, R16.2, U1.GND@0 (GND), U1.GND@1 (GND), U1.GND@2 (GND), U2.2 (GND), U4.3 (GND), U5.7 (GND), U5.GND
GPS-RX: J1.4 (RXA), S2.2
GPS-TX: J1.3 (TXA), S2.5
GRXI: S2.6, U1.D5 (*D5)
GTXO: S2.3, U1.D4
HV_SCL: Q2.3 (D), R5.2, U1.A5, U1.SCL
HV_SDA: Q1.3 (D), R4.2, U1.A4, U1.SDA
INT-PRESSURE: U4.6 (INT1)
LIGHT: R10.2, U1.A1, U3.E (E1)
unnamed: JP10-DNP.3, R14.2
unnamed: JP10-DNP.2, R13.2
unnamed: D1.A, R1.2
unnamed: JP9-DNP.3, R11.2
unnamed: C6.1, U4.2 (CAP)
unnamed: D3.A, R6.2
unnamed: JP9-DNP.4, R12.1
unnamed: JP10-DNP.5, R15.1
unnamed: JP10-DNP.4, R16.1
PWR_CTL: R9.1, U1.D6 (*D6)
RAIN: D5.2 (A), D6.1 (C), R11.1, U1.D2
RAIN2: JP9-DNP.2
RAIN5: JP9-DNP.5
RAW: C13.A (+), R8.1, U1.VIN, U2.1 (IN), U2.3 (EN)
RXI: S2.4, U1.RX
SCL: Q2.2 (S), R2.2, U4.8 (SCL), U5.SCK
SDA: Q1.2 (S), R3.2, U4.7 (SDA), U5.DATA
STAT1: R1.1, U1.D7
STAT2: R6.1, U1.D8
TXO: S2.1, U1.TX
V_BATT: J1.5 (VBATT), JP2.2
WDIR: D7.2 (A), D8.1 (C), R13.1, R17.2, U1.A0
WSPEED: D9.2 (A), D10.1 (C), R14.1, U1.D3 (*D3)

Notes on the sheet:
Max Voltage Input: 16VDC
Max Current Output: 500mA
N. Seidle
Read Address:
Write Address:
7-bit I2C Address:
0x60
0xC1
0xC0
7-bit I2C Address is 0x40
I2C write is 0x80
I2C read is 0x81
1.5 to 3.5V
External Batt Bckup
Sensors
Power
Conversion
Arduino
Changes on v1.1:
Removed TEMT6000 light sensor
Added 3.3V hook to A3 for 5>VCC>3.3V operation
Corrected GP-635T footprint
Removed 3.6V Zener
V1.1
Digital Pins 4 and 5 are used for software serial with switch is set to "Soft".

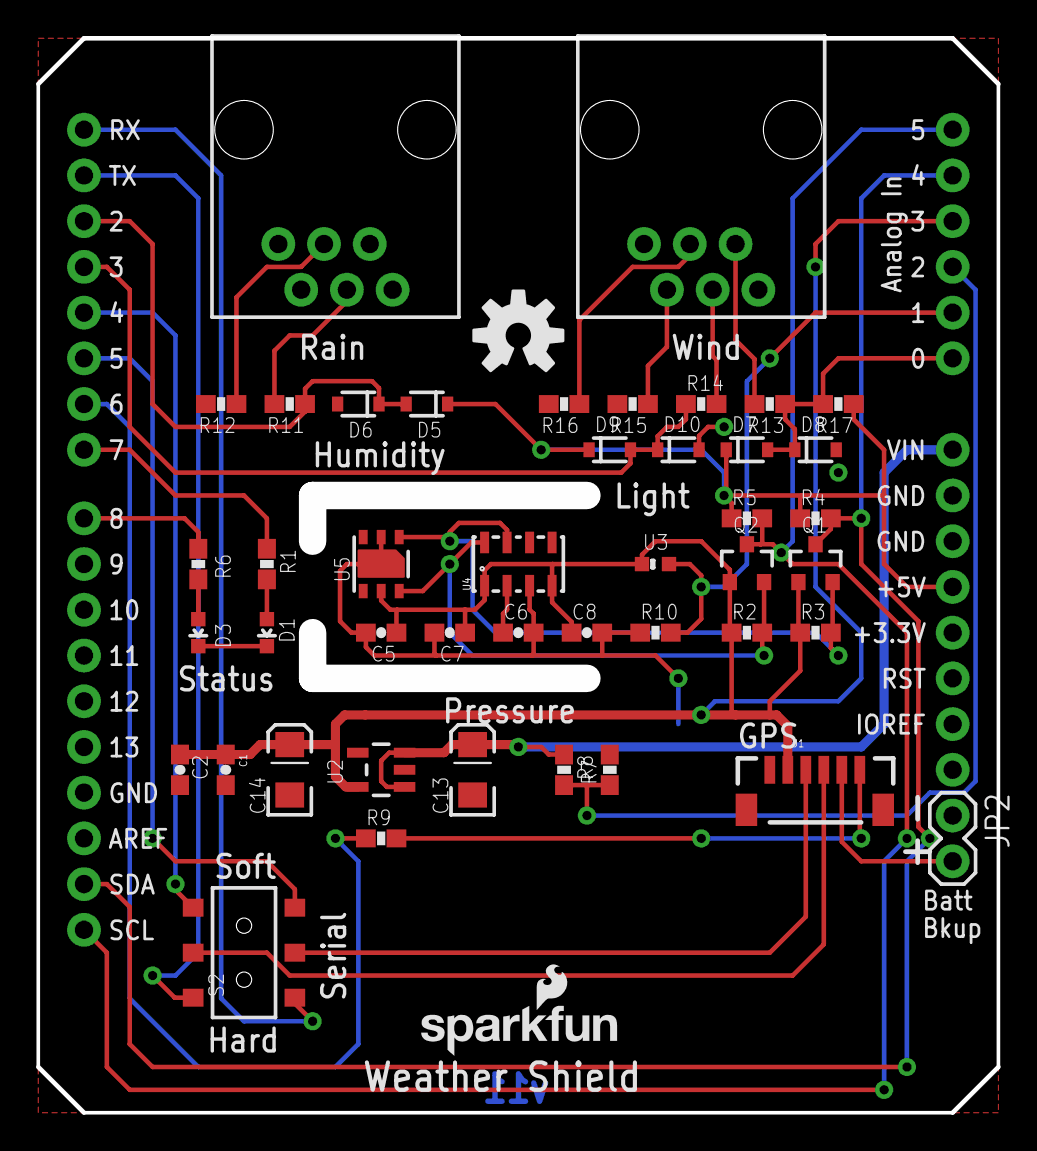
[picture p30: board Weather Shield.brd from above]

Board: 2 copper layers, 53.3 x 59.7 mm, 48 parts (0 on the bottom side), 33 nets.

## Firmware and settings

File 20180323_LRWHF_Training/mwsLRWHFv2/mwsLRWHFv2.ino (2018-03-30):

#include <TinyGPS++.h>

/* 
 Weather Shield Example
 By: Nathan Seidle
 SparkFun Electronics
 Date: November 16th, 2013
 License: This code is public domain but you buy me a beer if you use this and we meet someday (Beerware license).
 
 Much of this is based on Mike Grusin's USB Weather Board code: https://www.sparkfun.com/products/10586
 
 This code reads all the various sensors (wind speed, direction, rain gauge, humidty, pressure, light, batt_lvl)
 and reports it over the serial comm port. This can be easily routed to an datalogger (such as OpenLog) or
 a wireless transmitter (such as Electric Imp).
 
 Measurements are reported once a second but windspeed and rain gauge are tied to interrupts that are
 calcualted at each report.
 
 This example code assumes the GP-635T GPS module is attached.
 
 */

#include <Wire.h> //I2C needed for sensors
#include "MPL3115A2.h" //Pressure sensor
#include "HTU21D.h" //Humidity sensor
#include <SoftwareSerial.h> //Needed for GPS
#include <TinyGPS++.h> //GPS parsing



TinyGPSPlus gps;

//For Arduino Uno
//static const int RXPin = 5, TXPin = 4; //GPS is attached to pin 4(TX from GPS) and pin 5(RX into GPS)
//For Arduino Mega
static const int RXPin = 50, TXPin = 51; //GPS is attached to pin 7(TX from GPS) and pin 6(RX into GPS)
SoftwareSerial ss(RXPin, TXPin); 

MPL3115A2 myPressure; //Create an instance of the pressure sensor
HTU21D myHumidity; //Create an instance of the humidity sensor

//Hardware pin definitions
//-=-=-=-=-=-=-=-=-=-=-=-=-=-=-=-=-=-=-=-=-=-=-=-=-=-=-=-=
// digital I/O pins
const byte RAIN = 2;
const byte WSPEED = 3;
const byte GPS_PWRCTL = 6; //Pulling this pin low puts GPS to sleep but maintains RTC and RAM
//For Arduino Uno Only
//const byte STAT1 = 7;
//to be removed if using a GSM board
//const byte STAT2 = 8;

// analog I/O pins
const byte WDIR = A0;
const byte LIGHT = A1;
const byte BATT = A2;
const byte REFERENCE_3V3 = A3;
//-=-=-=-=-=-=-=-=-=-=-=-=-=-=-=-=-=-=-=-=-=-=-=-=-=-=-=-=

//Global Variables
//-=-=-=-=-=-=-=-=-=-=-=-=-=-=-=-=-=-=-=-=-=-=-=-=-=-=-=-=
long lastSecond; //The millis counter to see when a second rolls by
long loopMSecond; //time it took to loop once in millis
byte seconds; //When it hits 60, increase the current minute
byte seconds_2m; //Keeps track of the "wind speed/dir avg" over last 2 minutes array of data
byte minutes; //Keeps track of where we are in various arrays of data
byte minutes_5m; //Keeps track of where we are in rain5min over last 5 minutes array of data
byte minutes_10m; //Keeps track of where we are in wind gust/dir over last 10 minutes array of data
byte minutes_30m; //Keeps track of where we are in wind gust/dir over last 30 minutes array of data

long lastWindCheck = 0;
volatile long lastWindIRQ = 0;
volatile byte windClicks = 0;

//We need to keep track of the following variables:
//Wind speed/dir each update (no storage)
//Wind gust/dir over the day (no storage)
//Wind speed/dir, avg over 2 minutes (store 1 per second)
//Wind gust/dir over last 10 minutes (store 1 per minute)
//Rain over the past hour (store 1 per minute)
//Total rain over date (store one per day)

byte windspdavg[120]; //120 bytes to keep track of 2 minute average
int winddiravg[120]; //120 ints to keep track of 2 minute average
float windgust_10m[10]; //10 floats to keep track of 10 minute max
float windgust_30m[30]; //10 floats to keep track of 10 minute max
int windgustdirection_10m[10]; //10 ints to keep track of 10 minute max
int windgustdirection_30m[30]; //10 ints to keep track of 10 minute max
volatile float rainHour[60]; //60 floating numbers to keep track of 60 minutes of rain
volatile float rain5min[5]; //5 floating numbers to keep track of 5 minutes of rain
volatile float rain30min[30]; //30 floating numbers to keep track of 30 minutes of rain

//These are all the weather values that wunderground expects:
int winddir = 0; // [0-360 instantaneous wind direction]
float windspeedms = 0; // [mph instantaneous wind speed]
float windgustms = 0; // [mph current wind gust, using software specific time period]
int windgustdir = 0; // [0-360 using software specific time period]
float windspdms_avg2m = 0; // [mph 2 minute average wind speed mph]
int winddir_avg2m = 0; // [0-360 2 minute average wind direction]
float windgustms_10m = 0; // [mph past 10 minutes wind gust mph ]
int windgustdir_10m = 0; // [0-360 past 10 minutes wind gust direction]
float humidity = 0; // [%]
float tempf = 0; // [temperature F]
float rainin = 0; // [rain inches over the past hour)] -- the accumulated rainfall in the past 60 min
volatile float dailyrainin = 0.0; // [rain inches so far today in local time]
volatile float rainin5min=0.0; // [rain inches so far last 5 minutes in local time]
volatile float rainin30min=0.0; // [rain inches so far last 30 minutes in local time]
//float baromin = 30.03;// [barom in] - It's hard to calculate baromin locally, do this in the agent
float pressure = 0;
//float dewptf; // [dewpoint F] - It's hard to calculate dewpoint locally, do this in the agent

float batt_lvl = 11.8; //[analog value from 0 to 1023]
float light_lvl = 455; //[analog value from 0 to 1023]
//Rain time stamp
int Rainindi=0;
//Variables used for GPS
//unsigned long age;
//int year;
//byte month, day, hour, minute, second, hundredths;

//Calibrate rain bucket here
//Rectangle raingauge from Sparkfun.com weather sensors
float rain_bucket_mm = 0.011*25.4;//Each dump is 0.011" of water
//float rain_bucket_mm = 0.011*25.4;//Each dump is 0.011" of water
//DAVISNET Rain Collector 2
//float rain_bucket_mm = 0.01*25.4;//Each dump is 0.01" of water


//huminity declaration
float tF=0.0;
float dP=0.0;
float dPF=0.0;
float hindex=0.0;

// volatiles are subject to modification by IRQs
volatile unsigned long raintime, rainlast, raininterval, rain, Rainindtime, Rainindlast;

//for loop
int i;
//-=-=-=-=-=-=-=-=-=-=-=-=-=-=-=-=-=-=-=-=-=-=-=-=-=-=-=-=

//Interrupt routines (these are called by the hardware interrupts, not by the main code)
//-=-=-=-=-=-=-=-=-=-=-=-=-=-=-=-=-=-=-=-=-=-=-=-=-=-=-=-=
void rainIRQ()
// Count rain gauge bucket tips as they occur
// Activated by the magnet and reed switch in the rain gauge, attached to input D2
{
  raintime = millis(); // grab current time
  raininterval = raintime - rainlast; // calculate interval between this and last event

    if (raininterval > 100) // ignore switch-bounce glitches less than 10mS after initial edge
  {
    //rain_bucket_mm=1.0;
    dailyrainin += rain_bucket_mm; 
    rainHour[minutes] += rain_bucket_mm; //Increase this minute's amount of rain
    rain5min[minutes_5m] += rain_bucket_mm; // increase this 5 mnts amout of rain
    rain30min[minutes_30m] += rain_bucket_mm; // increase this 30 mnts amout of rain
    rainlast = raintime; // set up for next event
  }

  //Rain or not (1 or 0)
  if(rainin >0)
  {
    Rainindi=1;
    Rainindtime = millis();
  }
  if(rainin ==0)
  {
    Rainindi=0; 
    Rainindlast = millis();
    Rainindlast = Rainindtime;
  }
}

// delta max = 0.6544 wrt dewPoint()
// 6.9 x faster than dewPoint()
// reference: http://en.wikipedia.org/wiki/Dew_point
double dewPointFast(double celsius, double humidity)
{
 double a = 17.271;
 double b = 237.7;
 double temp = (a * celsius) / (b + celsius) + log(humidity*0.01);
 double Td = (b * temp) / (a - temp);
 return Td;
}

double heatIndex(double tempF, double humidity)
{
  double c1 = -42.38, c2 = 2.049, c3 = 10.14, c4 = -0.2248, c5= -6.838e-3, c6=-5.482e-2, c7=1.228e-3, c8=8.528e-4, c9=-1.99e-6  ;
  double T = tempF;
  double R = humidity;

  double A = (( c5 * T) + c2) * T + c1;
  double B = ((c7 * T) + c4) * T + c3;
  double C = ((c9 * T) + c8) * T + c6;

  double rv = (C * R + B) * R + A;
  return rv;
}

void wspeedIRQ()
// Activated by the magnet in the anemometer (2 ticks per rotation), attached to input D3
{
  if (millis() - lastWindIRQ > 10) // Ignore switch-bounce glitches less than 10ms (142MPH max reading) after the reed switch closes
  {
    lastWindIRQ = millis(); //Grab the current time
    windClicks++; //There is 1.492MPH for each click per second.
  }

}



void setup()
{
  //Switch on the GPS
  pinMode(GPS_PWRCTL, OUTPUT);
  digitalWrite(GPS_PWRCTL, HIGH); //Pulling this pin low puts GPS to sleep but maintains RTC and RAM

  //Start Serial port reporting
  Serial.begin(9600);

  // set up the LCD's number of columns and rows:
//  lcd.begin(16, 2);
//  lcd.backlight();
//  lcd.print("Start MWS");

  //Start software serial for GPS
  //Begin listening to GPS over software serial at 9600. This should be the default baud of the module.
  ss.begin(9600); 
  Serial.print(F("lon,lat,altitude,sats,date,GMTtime,winddir"));
  Serial.print(F(",windspeedms,windgustms,windgustdir,windspdms_avg2m,winddir_avg2m,windgustms_10m,windgustdir_10m"));
  Serial.print(F(",humidity,tempc,rainhourmm,raindailymm,rainindicate,rain5min,pressure,batt_lvl,light_lvl"));
  Serial.print(F(",DewPoint,HeatIndex,rain30min"));

  //For Arduino UNO Only
  //pinMode(STAT1, OUTPUT); //Status LED Blue
  //pinMode(STAT2, OUTPUT); //Status LED Green

  pinMode(WSPEED, INPUT_PULLUP); // input from wind meters windspeed sensor
  pinMode(RAIN, INPUT_PULLUP); // input from wind meters rain gauge sensor

  pinMode(REFERENCE_3V3, INPUT);
  pinMode(LIGHT, INPUT);

  //Configure the pressure sensor
  myPressure.begin(); // Get sensor online
  myPressure.setModeBarometer(); // Measure pressure in Pascals from 20 to 110 kPa
  myPressure.setOversampleRate(7); // Set Oversample to the recommended 128
  myPressure.enableEventFlags(); // Enable all three pressure and temp event flags 

    //Configure the humidity sensor
  myHumidity.begin();

  seconds = 0;
  lastSecond = millis();

  // attach external interrupt pins to IRQ functions
  attachInterrupt(0, rainIRQ, FALLING);
  attachInterrupt(1, wspeedIRQ, FALLING);

  // turn on interrupts
  interrupts();
  //digitalWrite(STAT2, HIGH); //Blink stat LED 1 second
  //delay(1000);
  //digitalWrite(STAT2, LOW); //Blink stat LED
  smartdelay(60000); //Wait 60 seconds, and gather GPS data
  minutes = gps.time.minute();
  minutes_5m = gps.time.minute();
  minutes_10m = gps.time.minute();
  minutes_30m = gps.time.minute();
  seconds = gps.time.second();
  lastSecond = millis();
  //digitalWrite(STAT2, HIGH); //Blink stat LED 1 second
  //delay(1000);
  //digitalWrite(STAT2, LOW); //Blink stat LED
 // lcd.print("Weather Station online!");
}

void loop()
{

 
  //Keep track of which minute it is
  loopMSecond = millis() - lastSecond;
  //digitalWrite(STAT2, HIGH); //Blink stat LED
  lastSecond = millis();

  //Take a speed and direction reading every second for 2 minute average
  seconds_2m += loopMSecond/1000;
  if(++seconds_2m > 119) seconds_2m = 0;

  //Calc the wind speed and direction every second for 120 second to get 2 minute average
  float currentSpeed = get_wind_speed();
  int currentDirection = get_wind_direction();
  windspdavg[seconds_2m] = (int)currentSpeed;
  winddiravg[seconds_2m] = currentDirection;

  //Check to see if this is a gust for the minute
  if(currentSpeed > windgust_10m[minutes_10m])
  {
    windgust_10m[minutes_10m] = currentSpeed;
    windgustdirection_10m[minutes_10m] = currentDirection;
  }


  //Check to see if this is a gust for the minute
  if(currentSpeed > windgust_30m[minutes_30m])
  {
    windgust_30m[minutes_30m] = currentSpeed;
    windgustdirection_30m[minutes_30m] = currentDirection;
  }
  
  //Check to see if this is a gust for the day
  if(currentSpeed > windgustms)
  {
    windgustms = currentSpeed;
    windgustdir = currentDirection;
  }
  seconds += loopMSecond/1000;
  if(++seconds > 59) seconds = 0;
  minutes += seconds/60;
  if(++minutes > 59) minutes = 0;
  minutes_5m += seconds/60;
  if(++minutes_5m > 4){
    //Report all readings every 5 minutes    
    //printWeather();  // debug tool
    minutes_5m = 0;
    for (i=0;i<5;i++) rain5min[i] = 0;
  }
  minutes_10m += seconds/60;
  if(++minutes_10m > 9){
    minutes_10m = 0;
    for (i=0;i<10;i++) windgust_10m[i] = 0;
  }
  minutes_30m += seconds/60;
  if(++minutes_30m > 29){
    //Report all readings every 5 minutes
    minutes_30m = 0;
    for (i=0;i<30;i++) rain30min[i] = 0;
  }

  rainHour[minutes] = 0; //Zero out this minute's rainfall amount
  rain5min[minutes_5m] = 0; //Zero out this minute's rain  
  rain30min[minutes_30m] = 0; //Zero out this minute's rain
  windgust_10m[minutes_10m] = 0; //Zero out this minute's gust
  //windgust_30m[minutes_30m] = 0; //Zero out this minute's gust
  

 
 
  //Report all readings
  printWeather();
  //Turn off stat LED
  //digitalWrite(STAT2, LOW); 
  //Wait 1 second, and gather GPS data
   rainin5min++;
  smartdelay(100); 
  delay(100);
}

//While we delay for a given amount of time, gather GPS data
static void smartdelay(unsigned long ms)
{
  unsigned long start = millis();
  do 
  {
    while (ss.available())
      gps.encode(ss.read());
  } 
  while (millis() - start < ms);
}


//Calculates each of the variables that wunderground is expecting
void calcWeather()
{
  //Calc winddir
  winddir = get_wind_direction();

  //Calc windspeed
  windspeedms = get_wind_speed();

  //Calc windgustms
  //Calc windgustdir
  //Report the largest windgust today
  windgustms = 0;
  windgustdir = 0;

  //Calc windspdms_avg2m
  float temp = 0;
  for(int i = 0 ; i < 120 ; i++)
    temp += windspdavg[i];
  temp /= 120.0;
  windspdms_avg2m = temp;

  //Calc winddir_avg2m
  temp = 0; //Can't use winddir_avg2m because it's an int
  for(int i = 0 ; i < 120 ; i++)
    temp += winddiravg[i];
  temp /= 120;
  winddir_avg2m = temp;

  //Calc windgustms_10m
  //Calc windgustdir_10m
  //Find the largest windgust in the last 10 minutes
  windgustms_10m = 0;
  windgustdir_10m = 0;
  //Step through the 10 minutes  
  for(int i = 0; i < 10 ; i++)
  {
    if(windgust_10m[i] > windgustms_10m)
    {
      windgustms_10m = windgust_10m[i];
      windgustdir_10m = windgustdirection_10m[i];
    }
  }

  //Calc humidity
  humidity = myHumidity.readHumidity();
  if(myHumidity.readTemperature())
  {
    tempf = myHumidity.readTemperature();
  } 
  else
  {
    //Calc tempf from pressure sensor
    tempf = myPressure.readTemp();
  }

  //Total rainfall for the day is calculated within the interrupt
  //Calculate amount of rainfall for the last 5 minutes
  rainin5min = 0;  
  for(int i = 0 ; i < 5 ; i++)
    rainin5min += rain5min[i];
    
  //Calculate amount of rainfall for the last 60 minutes
  rainin = 0;  
  for(int i = 0 ; i < 60 ; i++)
    rainin += rainHour[i];

  //Calculate amount of rainfall for the last 30 minutes
  rainin30min = 0;  
  for(int i = 0 ; i < 30 ; i++)
    rainin30min += rain30min[i];

  //Calc pressure
  pressure = myPressure.readPressure();

  //Calc light level
  light_lvl = get_light_level();

  //Calc battery level
  batt_lvl = get_battery_level();

  //calculate dewpoint
  float h = humidity;
  float t = tempf;

  dPF=(dewPointFast(t, h));
  //change c to 
  tF=((t*9)/5)+32;

  //calculate heat index
  hindex=heatIndex(tF,h);
}

//Returns the voltage of the light sensor based on the 3.3V rail
//This allows us to ignore what VCC might be (an Arduino plugged into USB has VCC of 4.5 to 5.2V)
float get_light_level()
{
  float operatingVoltage = analogRead(REFERENCE_3V3);

  float lightSensor = analogRead(LIGHT);

  operatingVoltage = 3.3 / operatingVoltage; //The reference voltage is 3.3V

  lightSensor = operatingVoltage * lightSensor;

  return(lightSensor);
}

//Returns the voltage of the raw pin based on the 3.3V rail
//This allows us to ignore what VCC might be (an Arduino plugged into USB has VCC of 4.5 to 5.2V)
//Battery level is connected to the RAW pin on Arduino and is fed through two 5% resistors:
//3.9K on the high side (R1), and 1K on the low side (R2)
float get_battery_level()
{
  float operatingVoltage = analogRead(REFERENCE_3V3);

  float rawVoltage = analogRead(BATT);

  operatingVoltage = 3.30 / operatingVoltage; //The reference voltage is 3.3V

  rawVoltage = operatingVoltage * rawVoltage; //Convert the 0 to 1023 int to actual voltage on BATT pin

  rawVoltage *= 4.90; //(3.9k+1k)/1k - multiple BATT voltage by the voltage divider to get actual system voltage

  return(rawVoltage);
}

//Returns the instataneous wind speed
float get_wind_speed()
{
  float deltaTime = millis() - lastWindCheck; //750ms

  deltaTime /= 1000.0; //Convert to seconds

  float windSpeed = (float)windClicks / deltaTime; //3 / 0.750s = 4

  windClicks = 0; //Reset and start watching for new wind
  lastWindCheck = millis();

  //windSpeed *= 1.492; //4 * 1.492 = 5.968MPH
  windSpeed *= 1.492; //4 * 1.492 = 5.968MPH
  windSpeed *= 1.609344; //5.968MPH * 1.609344 = 9.604564992KMPH
  windSpeed /= 3.6; //9.604564992KMPH / 3.6 = 2.66793472MPS

  return(windSpeed);
}

//Read the wind direction sensor, return heading in degrees
int get_wind_direction() 
{
  unsigned int adc;

  adc = analogRead(WDIR); // get the current reading from the sensor

  // The following table is ADC readings for the wind direction sensor output, sorted from low to high.
  // Each threshold is the midpoint between adjacent headings. The output is degrees for that ADC reading.
  // Note that these are not in compass degree order! See Weather Meters datasheet for more information.

  if (adc < 380) return (113);//NOT WORKING
  else if (adc < 393) return (68);//NOT WORKING
  else if (adc < 414) return (90);//NOT WORKING
  else if (adc < 456) return (90);//(158);//E is 90 degrees CW from North = 0
  else if (adc < 508) return (135);//SE is 135 degrees CW from North = 0
  else if (adc < 551) return (180);//(203);//S is 180 degrees CW from North = 0
  else if (adc < 615) return (45);//(180);//NE is 45 degrees CW from North = 0
  else if (adc < 680) return (23);//NOT WORKING
  else if (adc < 746) return (225);//(45);//SW is 225 degrees CW from North = 0
  else if (adc < 801) return (248);//NOT WORKING
  else if (adc < 833) return (0);//(225);//N is 0 degrees CW from North = 0
  else if (adc < 878) return (338);//NOT WORKING
  else if (adc < 913) return (325);//(0);//NW is 325 degrees CW from North = 0
  else if (adc < 940) return (293);//NOT WORKING
  else if (adc < 967) return (270);//(315);//W is 270 degrees CW from North = 0
  else if (adc < 990) return (270);//NOT WORKING
  else return (-1); // error, disconnected?
}


//Prints the various variables directly to the port
//I don't like the way this function is written but Arduino doesn't support floats under sprintf
void printWeather()
{
  calcWeather(); //Go calc all the various sensors

  Serial.println();
  Serial.print(gps.location.lng(), 6);//[0]
  Serial.print(",");
  Serial.print(gps.location.lat(), 6);//[1]
  Serial.print(",");
  Serial.print(gps.altitude.meters());//[2]
  Serial.print(",");
  Serial.print(gps.satellites.value());//[3]

  char sz[32];
  Serial.print(",");
  sprintf(sz, "%02d-%02d-%02d", gps.date.year(), gps.date.month(), gps.date.day());//[4]
  Serial.print(sz);

  Serial.print(",");
  sprintf(sz, "%02d:%02d:%02d", gps.time.hour(), gps.time.minute(), gps.time.second());//[5]
  Serial.print(sz); 

  Serial.print(",");
  Serial.print(get_wind_direction());//[6]
  Serial.print(",");
  Serial.print(get_wind_speed(), 1);//[7]
  Serial.print(",");
  Serial.print(windgustms, 1);//[8]
  Serial.print(",");
  Serial.print(windgustdir);//[9]
  Serial.print(",");
  Serial.print(windspdms_avg2m, 1);//[10]
  Serial.print(",");
  Serial.print(winddir_avg2m);//[11]
  Serial.print(",");
  Serial.print(windgustms_10m, 1);//[12]
  Serial.print(",");
  Serial.print(windgustdir_10m);//[13]
  Serial.print(",");
  Serial.print(humidity, 1);//[14]
  Serial.print(",");
  Serial.print(tempf, 1);//[15] Celsius
  Serial.print(",");
  Serial.print(rainin, 3);//[16] hourly
  Serial.print(",");
  Serial.print(dailyrainin, 3);//[17]
  Serial.print(",");
  Serial.print(Rainindi,1);//[18] 5min indicatior (flag 0/1)
  Serial.print(",");
  Serial.print(rainin5min,3);//[19] 5min rain (mm/5min)
  Serial.print(",");
  Serial.print(pressure, 2);//[20]
  Serial.print(",");
  Serial.print(batt_lvl, 2);//[21]
  Serial.print(",");
  Serial.print(light_lvl, 2);//[22]
  Serial.print(",");

  Serial.print(dPF); //[23]
  Serial.print(",");
  Serial.print(hindex);//[24]
  Serial.print(",");
  //Serial.print(rainin5min,3);
  Serial.print(rainin30min, 3);//[25] 3 min rain (mm/30)
  //--------------------------
  //PRINT TO LCD
  //--------------------------

//  lcd.clear();
 // lcd.print(F("Lon:"));
 // lcd.print(gps.location.lng(), 6);
//lcd.setCursor(0, 2);
 // lcd.print(F("Lat:"));
//  lcd.print(gps.location.lat(), 6);
 // delay(5000);

 // lcd.clear();
 // sprintf(sz, "%02d-%02d-%02d", gps.date.year(), gps.date.month(), gps.date.day());
//  lcd.print(sz);
//  lcd.setCursor(0, 2);
 // sprintf(sz, "%02d:%02d:%02d", gps.time.hour(), gps.time.minute(), gps.time.second());
 // lcd.print(sz);
 // lcd.print(F(" GMT"));
  delay(5000);
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

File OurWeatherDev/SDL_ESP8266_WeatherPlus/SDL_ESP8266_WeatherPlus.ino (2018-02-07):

// Filename WeatherPlus.ino
// Version 1.23 August 2017
// SwitchDoc Labs, LLC
//

//
// Started From:
// Filename ArduinoConnectServer.ino
// Version 1.5 08/15/13 RV MiloCreek
//


#define WEATHERPLUSESP8266VERSION "023"

// define DEBUGPRINT to print out lots of debugging information for WeatherPlus.
#undef DEBUGPRINT


// Change this to undef if you don't have the OLED present0
#define OLED_Present

// BOF preprocessor bug prevent - insert on top of your arduino-code
#if 1
__asm volatile ("nop");
#endif

// Board options

#pragma GCC diagnostic ignored "-Wwrite-strings"

extern "C" {
#include "user_interface.h"
}
//#include "Time/TimeLib.h"
#include "TimeLib.h"

#include <ESP8266WiFi.h>

//needed for library
#include <DNSServer.h>
#include <ESP8266WebServer.h>



#include "WiFiManager.h"          //https://github.com/tzapu/WiFiManager

//gets called when WiFiManager enters configuration mode


//void configModeCallback (WiFiManager *myWiFiManager)
void configModeCallback ()
{

  Serial.println("Entered config mode");

  Serial.println(WiFi.softAPIP());

}

// OTA updated
#include <ESP8266WiFiMulti.h>



#include <ESP8266HTTPClient.h>
#include <ESP8266httpUpdate.h>

#include <EEPROM.h>


#include "config.h"




#include <Wire.h>

#include <Arduino.h> //needed for Serial.println

// debug the REST library

#define DEBUG_MODE 1

#include "aREST.h"

#include <string.h>

// display modes
#define DISPLAY_POWERUP 0
#define DISPLAY_IPDISPLAY 1
#define DISPLAY_WEATHER_SMALL 2
#define DISPLAY_WEATHER_MEDIUM 3
#define DISPLAY_WEATHER_LARGE 4
#define DISPLAY_STATUS 5
#define DISPLAY_ACCESSPOINT 6
#define DISPLAY_WEATHER_DEMO 7
#define DISPLAY_TRYING_AP 8
#define DISPLAY_FAILING_AP 9
#define DISPLAY_DATETIME 10
#define DISPLAY_UPDATING 11
#define DISPLAY_NO_UPDATE_AVAILABLE 12
#define DISPLAY_NO_UPDATE_FAILED 13
#define DISPLAY_UPDATE_FINISHED 14
#define DISPLAY_SUNAIRPLUS 16
#define DISPLAY_WXLINK 17

#define DEBUG


// Rest Interface


#define PREFIX ""

String RestTimeStamp;
String RestDataString;
String Version;

//----------------------------------------------------------------------
//Local WiFi


int WiFiSetupFlag = 0;

String APssid;

String Wssid;
String WPassword;

WiFiServer server(WEB_SERVER_PORT);



//----------------------------------------------------------------------


int blinkPin = 0;                // pin to blink led at each reading
// Create an instance of the server


// Create aREST instance
aREST rest = aREST();
// commands are functions that get called by the webserver framework
// they can read any posted data from client, and they output to server




#include "elapsedMillis.h"

elapsedMillis timeElapsed; //declare global if you don't want it reset every time loop

elapsedMillis timeElapsed300Seconds; //declare global if you don't want it reset every time loop

// BMP180 / BMP280 Sensor
// Both are stored in BMP180 variables
//

#include "MAdafruit_BMP280.h"
#include "MAdafruit_BMP085.h"
Adafruit_BMP280 bme;

Adafruit_BMP085 bmp;
#define SENSORS_PRESSURE_SEALEVELHPA 1015.00
float altitude_meters;
float BMP180_Temperature;
float BMP180_Pressure;
float BMP180_Altitude;

bool BMP180Found;
bool BMP280Found;


int EnglishOrMetric;   // 0 = English units, 1 = Metric

int WeatherDisplayMode;

// DS3231 Library functions

#include "RtcDS3231.h"

RtcDS3231 Rtc;


// AM2315

float AM2315_Temperature;
float AM2315_Humidity;
float dewpoint;

#include "SDL_ESP8266_HR_AM2315.h"


SDL_ESP8266_HR_AM2315 am2315;
float dataAM2315[2];  //Array to hold data returned by sensor.  [0,1] => [Humidity, Temperature]

boolean AOK;  // 1=successful read

const char *monthName[12] = {
  "Jan", "Feb", "Mar", "Apr", "May", "Jun",
  "Jul", "Aug", "Sep", "Oct", "Nov", "Dec"
};

// MOD1016-G Lightning Detector AS3935
/*
#include "AS3935.h"

void printAS3935Registers();


// Interrupt handler for AS3935 irqs
// and flag variable that indicates interrupt has been triggered
// Variables that get changed in interrupt routines need to be declared volatile
// otherwise compiler can optimize them away, assuming they never get changed
void AS3935Irq();
volatile int AS3935IrqTriggered;

// Library object initialization First argument is interrupt pin, second is device I2C address
AS3935 AS3935(3, 0x03);



void printAS3935Registers()
{
  int noiseFloor = AS3935.getNoiseFloor();
  int spikeRejection = AS3935.getSpikeRejection();
  int watchdogThreshold = AS3935.getWatchdogThreshold();
  Serial.print("Noise floor is: ");
  Serial.println(noiseFloor, DEC);
  Serial.print("Spike rejection is: ");
  Serial.println(spikeRejection, DEC);
  Serial.print("Watchdog threshold is: ");
  Serial.println(watchdogThreshold, DEC);
}

// this is irq handler for AS3935 interrupts, has to return void and take no arguments
// always make code in interrupt handlers fast and short
void AS3935Irq()
{
  AS3935IrqTriggered = 1;
}
*/

// Station Name

String stationName;
String adminPassword;

// Health Indications for WeatherPlus

int heapSize;

// WeatherUnderground

String WeatherUnderground_StationID;
String WeatherUnderground_StationKey;
int lastMessageID;



// WeatherRack


float windSpeedMin;
float windSpeedMax;
float windGustMin;
float windGustMax;
float windDirectionMin;
float windDirectionMax;



float currentWindSpeed;
float currentWindGust;
float currentWindDirection;

float rainTotal;


float rainCalendarDay;
int lastDay;

float startOfDayRain;

#include "SDL_RasPiGraphLibrary.h"
// setup the RasPiConnect Graph Arrays
SDL_RasPiGraphLibrary windSpeedGraph(10, SDL_MODE_LABELS);
SDL_RasPiGraphLibrary windGustGraph(10, SDL_MODE_LABELS);
SDL_RasPiGraphLibrary windDirectionGraph(10, SDL_MODE_LABELS);


char windSpeedBuffer[150];  // wind speed graph
char windGustBuffer[150];  // wind speed graph
char windDirectionBuffer[150];  // wind speed graph





// WeatherRack

// LED connected to digital GPIO 0
int WpinLED = 0;
// Anenometer connected to GPIO 14
int pinAnem = 14;
// Rain Bucket connected to  GPIO 12
int pinRain = 12;


#include "OWMAdafruit_ADS1015.h"


Adafruit_ADS1015 ads1015(0x49);

int current_quality = -1;
Adafruit_ADS1115 adsAirQuality(0x48);



long currentAirQuality;
long currentAirQualitySensor;
int INTcurrentAirQualitySensor;
bool AirQualityPresent = false;

#include "AirQualitySensor.h"

#include "SDL_Weather_80422.h"


//SDL_Weather_80422 weatherStation(pinAnem, pinRain, 0, 0, A0, SDL_MODE_INTERNAL_AD );
SDL_Weather_80422 weatherStation(pinAnem, pinRain, 0, 0, A0, SDL_MODE_I2C_ADS1015 );


// SDL_MODE_I2C_ADS1015
//

// RasPiConnect








long messageCount;

static uint8_t mac[] = LOCALMAC;
static uint8_t ip[] = LOCALIP;

// this is our current command object structure.  It is only valid inside void jsonCmd
typedef struct {
  char ObjectID[40];
  char ObjectFlags[40];
  char ObjectAction[40];
  char ObjectName[40];
  char ObjectServerID[40];
  char Password[40];
  char ObjectType[40];
  char Validate[40];
} currentObjectStructure;

char *md5str;
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

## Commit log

2015-01-06 Added a testSMS code and the main Arduino code (no SMS yet)
2015-03-07 Added experimental weewx MWS driver, to copy in build/lib/drivers/ it seems
2015-03-08 Added OSHW: Weather Shield and Rain Gauge
    [Assem2.IGS, Assem2.SLDASM, Assem2.STEP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]
2015-04-03 updated LCD display, changed pressure display unit to hPa
2015-04-03 More accurate time loops for value aggregation from sensors
2015-04-03 Corrected the wind direction from 16 to 8 directions
    [mws.ino, mwsLCD.ino]
2015-04-03 updated LCD display with smaller memory footprint
2015-04-03 Fixed date display bug
    [mwsLCD.ino]
2015-04-03 Added F() in Serial.print(\string\)
2015-04-03 Trying to correct for IRQ glitch in the rain gauge input
    [mwsLCD.ino]
2015-04-08 Updated with radiation shield and raing gauge 3D print files
    [Base3.scad, Base3.stl, Bottom_part.STL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]
2015-05-20 Added I2C board for 2-wire display control
2015-05-21 Working solution for Arduino Mega
2015-05-22 Added a new raingauge 3D file from thingyverse
    [rainmeter.scad, rainmeter.stl, rainmeter_plate_lowres.stl]
2015-06-23 Added Version 1 (Arduino Uno, no comms) used initially by LRWHF
2015-06-23 Modified for using driver mws.py for weewx integration
2015-06-25 Added Version 2 using Arduino Mega and LCD display
2015-06-25 fixed weewx driver
2015-06-25 Create readme.txt
    Info to disable Arduino reset on Serial open
2015-06-26 trying to make the weewx driver work
2015-07-02 bug fixing reading senteces
    [mws.py]
2015-07-02 bug fixing reading sentences
    [mws.py]
2015-07-02 still debugging for user driver
2015-07-07 big fix the GPS
    [mwsLRWHFv2.ino]
2015-07-07 Update readme.md
    More specs discussion from Arduino Uno to Mega
2015-07-07 bug fixed for the GPS
    [mwsLRWHFv2.ino]
2015-07-07 bug fixed for the GPS (clean up)
    [mwsLRWHFv2.ino]
2015-07-08 Update readme.md
    LCD wiring info OK
2015-07-12 Added example PhP code for Arduino data upload
2015-07-20 changed raingauge switch glitch time protection from 10ms to 10ms
    [mwsLRWHFv2.ino]
2015-07-21 fixed 5min reporting rain
    [mwsLRWHFv2.ino]
2015-07-21 Added sample data extraction from raw information (careful the date format is not standard raw output)
    [MetDept1.csv]
2015-07-21 Added sample data extraction from raw information for LRWHF MWS v2
2015-08-04 Added nice skin from http://en.blauesledersofa.de/2015/03/flat-template-for-weewx/
2015-08-07 Update including fixes for 5 minutes rainfall reporting
    [mws.py, mwsLRWHFv2.ino]
2015-11-06 Sending alert SMS to 5 phone numbers when hourly rainfall is more than 25 mm/h
2016-03-24 submitting initial version of the IWMI Arduino SMS alert system
2016-03-31 Added radiationshield1 from thingiverse, with 3D files
    [AM2315_mount_V1.stl, HTM2500_mount_V1.stl, HTU21D_mount_V1.stl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]
2016-04-11 Renamed ino file as holding folder for Arduino IDE
2016-05-02 trying to fix mm/h non-reporting alert bug
    [mwsIWMIv3.ino]
2016-05-07 bug fix winddir reporting
    [mwsIWMIv3.ino]
2016-05-10 update fix bug sprintf .3f to s
    [mwsIWMIv3.ino]
2016-06-08 Add another raingauge and a wind speed for 3D printing
    [ball_holder.stl, cone.stl, ground_frame_v2.stl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]
2016-06-20 Latest update from Lahiru, fixed SMS sending
    [mwsIWMIv3.ino]
2017-03-09 add raingauge 4 from http://www.thingiverse.com/thing:2163969
    [Base.stl, Bucket.stl, Funnel.stl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]
2017-05-09 Added new 3D printed raingauge
    [BOTTOM CAP.SLDPRT, COLLECTOR.SLDPRT, PVC PIPE.SLDPRT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]
2017-08-09 Uploaded all stations configs
    [CONFIG.TXT]
2017-10-02 Added 20170927 field trip
    [CONFIG.TXT]
2017-10-03 Added data from SIRI_SADANANDA monk school
    [CONFIG.TXT]
2017-11-02 Adding actual field trip, will update until I complete the trip on 20171104
    [CONFIG.TXT]
2017-11-08 rewritten Weather Printing functions and added a sendWeather() function for SMS reporting to server
2018-03-30 Added new code with Dewpoint, heat index and rain30min from trainees
    [WS_Data.xlsx]

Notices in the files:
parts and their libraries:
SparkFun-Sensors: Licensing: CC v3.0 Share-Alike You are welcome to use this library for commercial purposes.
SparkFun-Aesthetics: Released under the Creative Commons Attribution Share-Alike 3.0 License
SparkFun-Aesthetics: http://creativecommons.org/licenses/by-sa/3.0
